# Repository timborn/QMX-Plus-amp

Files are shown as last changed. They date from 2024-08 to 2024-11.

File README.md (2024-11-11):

# QMX-amp
The QMX+ is a very nice radio kit from QPR Labs
https://qrp-labs.com/

This amp is designed by Ron Taylor, WA7GIL.  It should fit inside the empty
space in the case.

doc/original-drawings shows the original design sketchs

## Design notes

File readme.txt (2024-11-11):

Mon Nov 11 14:53:17 MST 2024
----------------------------
Changed the name of this project to QMX-Plus-amp to remove confusion with QMX.

Mon Aug 19 12:31:12 MST 2024
----------------------------
- silk screen is landing in all kinds of unhelpful places
- RF paths need wide copper.  How wide?  Figure out netclasses
- +12V probably needs a wide path as well for all that current (HOW MUCH?)
- want K1 & K2 to be *identical* even tho they appear in multiple schematic
  pages.  I want the control signals on one, and the RF paths on another.
  So far all I get are complaints about duplicate symbols, even when I 
  copy / paste special.

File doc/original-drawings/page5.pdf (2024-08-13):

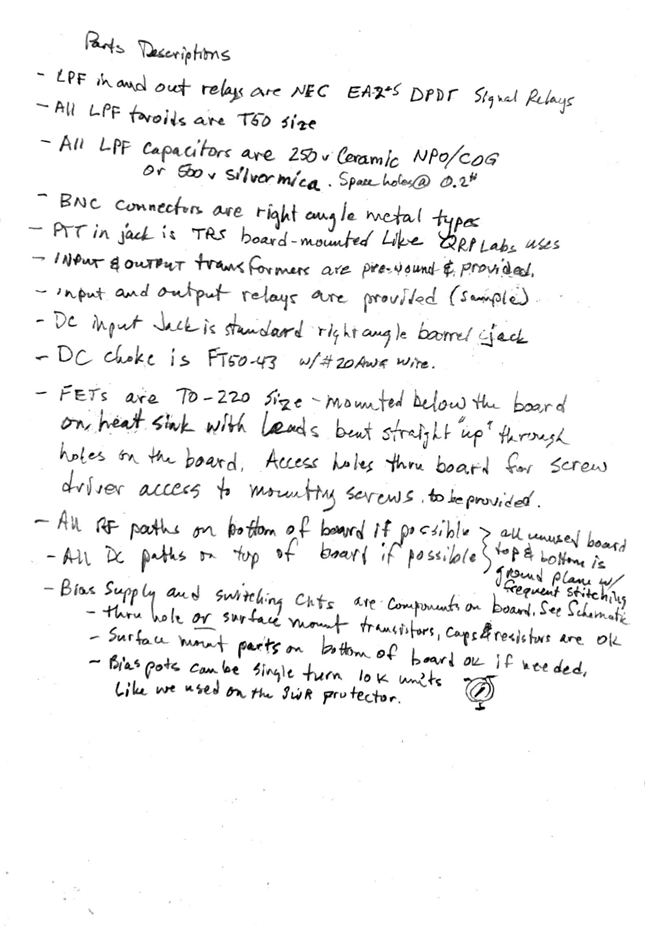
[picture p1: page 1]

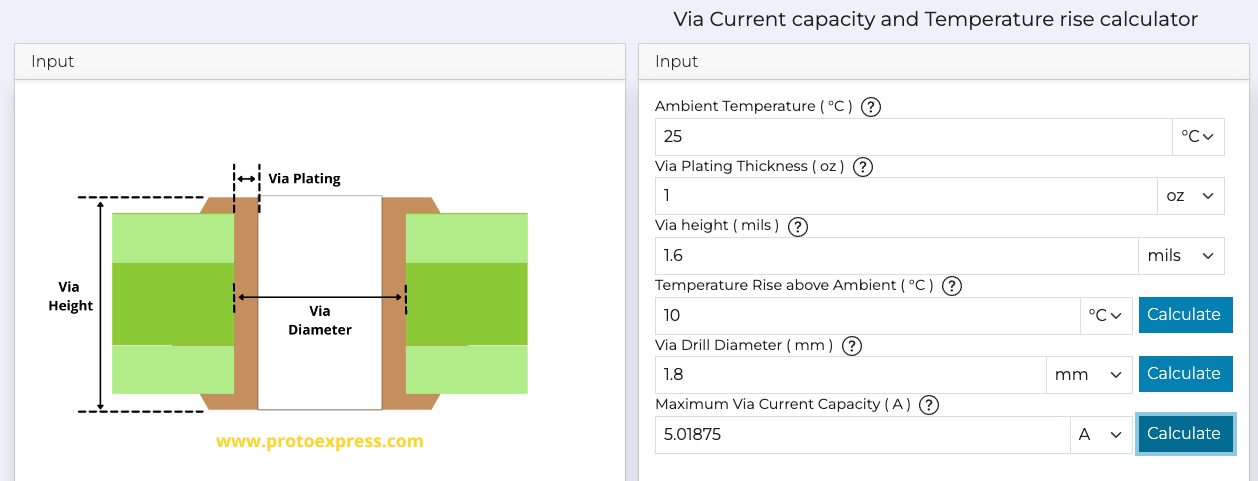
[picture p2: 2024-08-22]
doc/ViaCalcFor5APwr_designertools.app.protoexpress.com.jpg

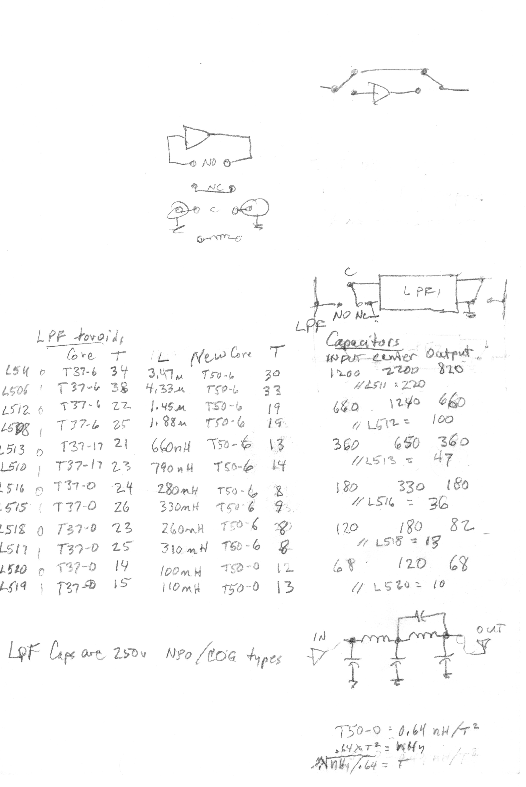
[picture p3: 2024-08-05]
doc/original-drawings/page6.jpg

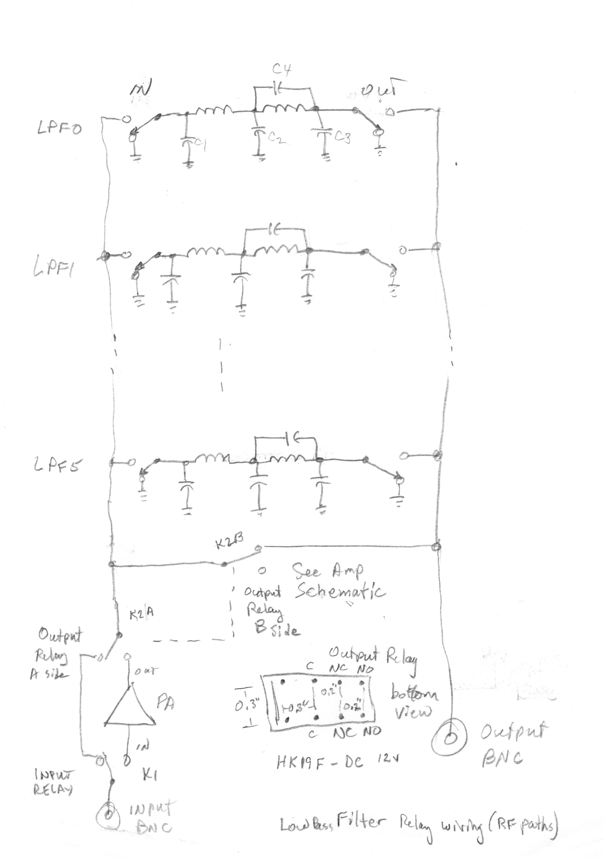
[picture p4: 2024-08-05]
doc/original-drawings/page2.jpg

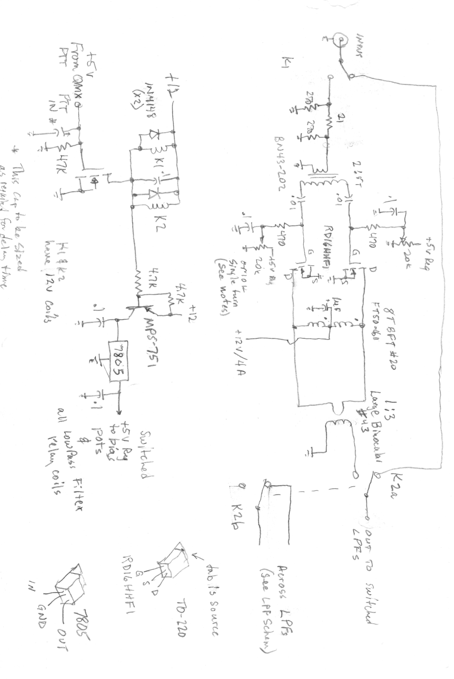
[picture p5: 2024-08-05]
doc/original-drawings/page4.jpg

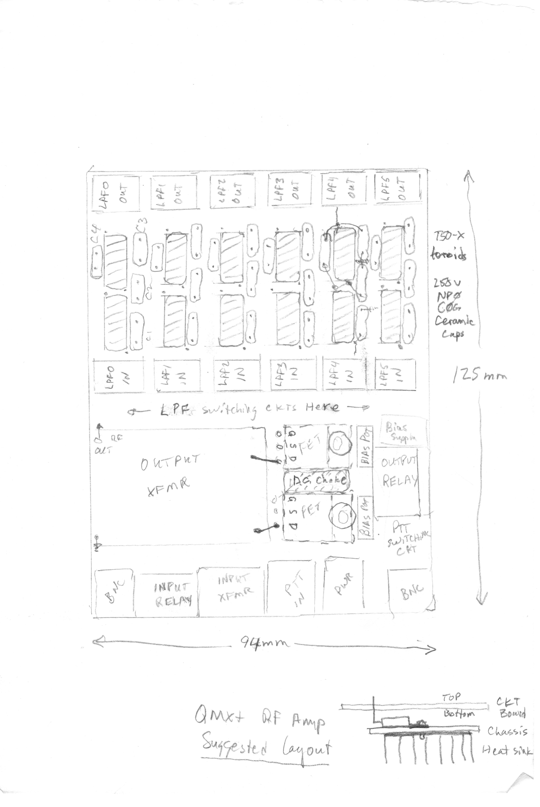
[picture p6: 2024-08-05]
doc/original-drawings/page3.jpg

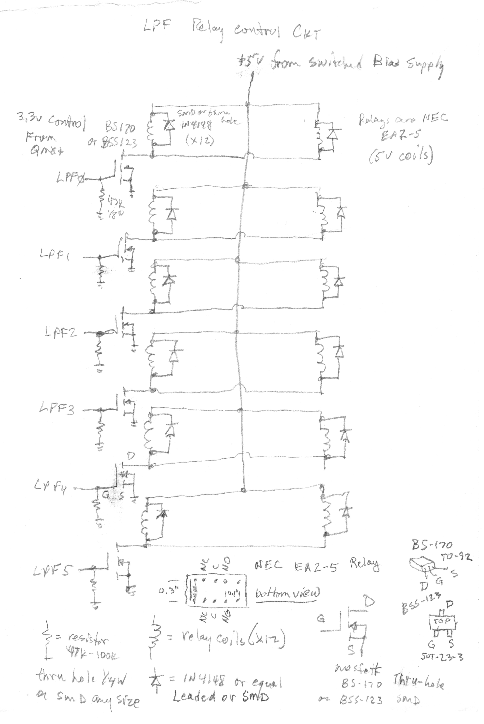
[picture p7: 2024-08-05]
doc/original-drawings/page1.jpg

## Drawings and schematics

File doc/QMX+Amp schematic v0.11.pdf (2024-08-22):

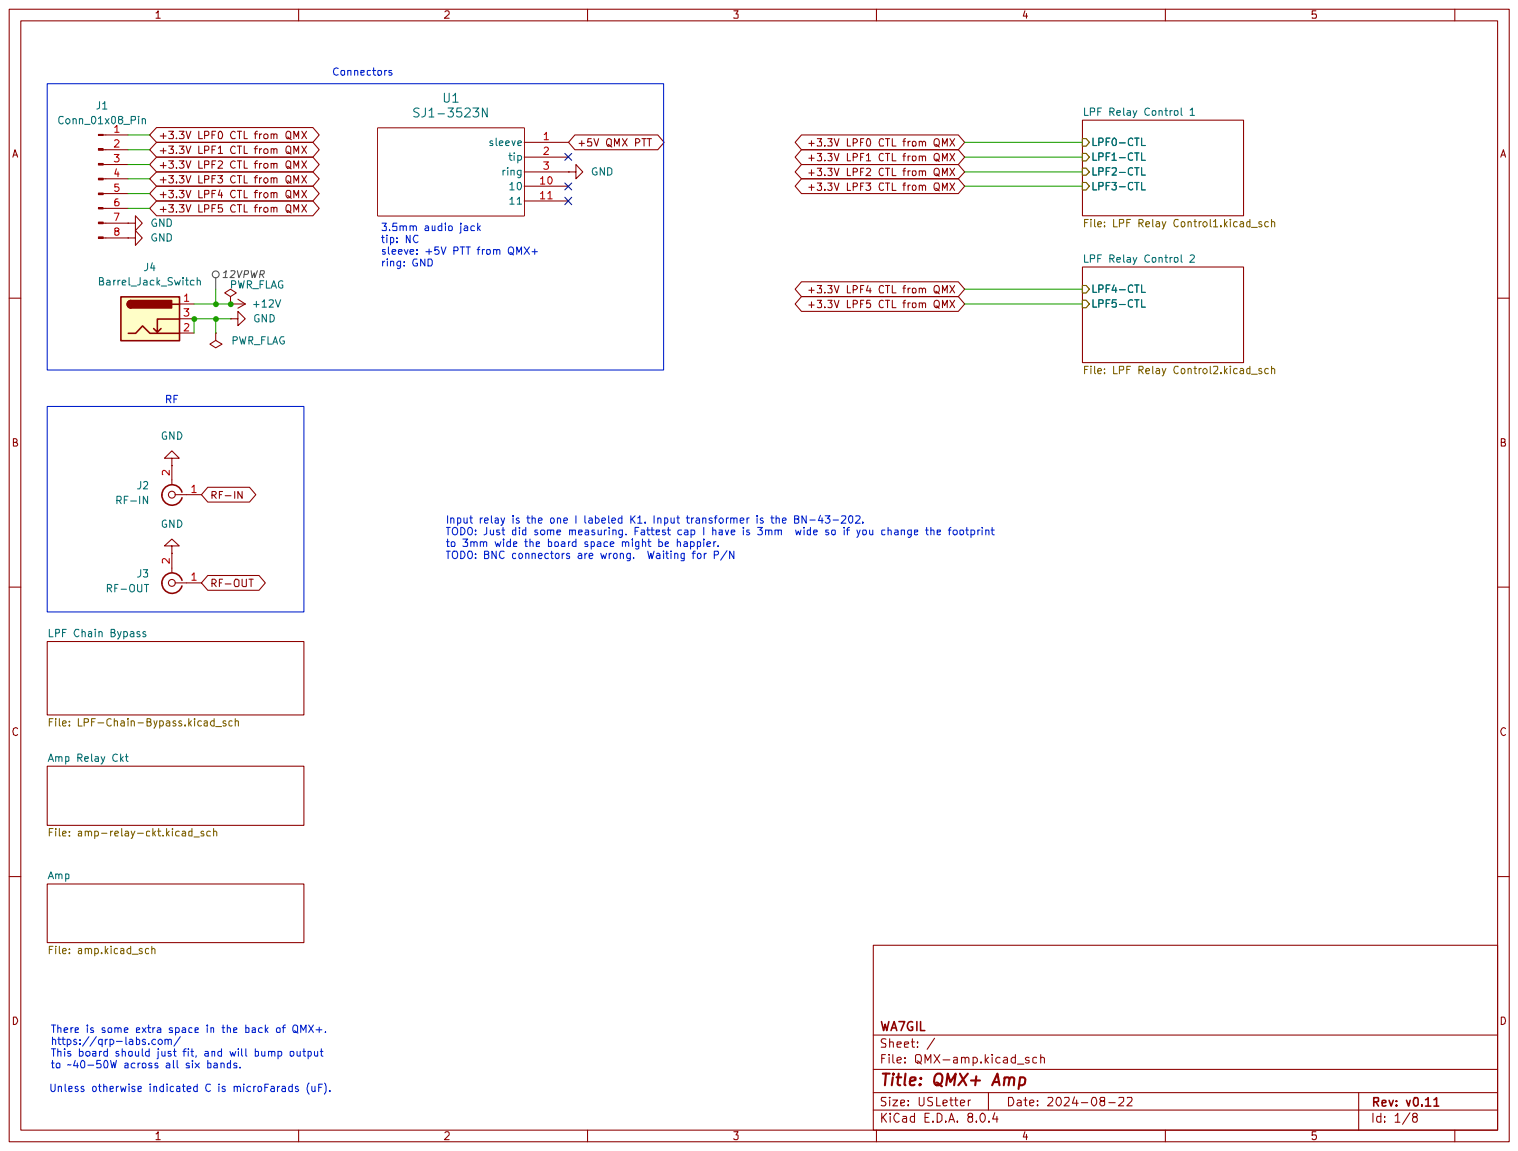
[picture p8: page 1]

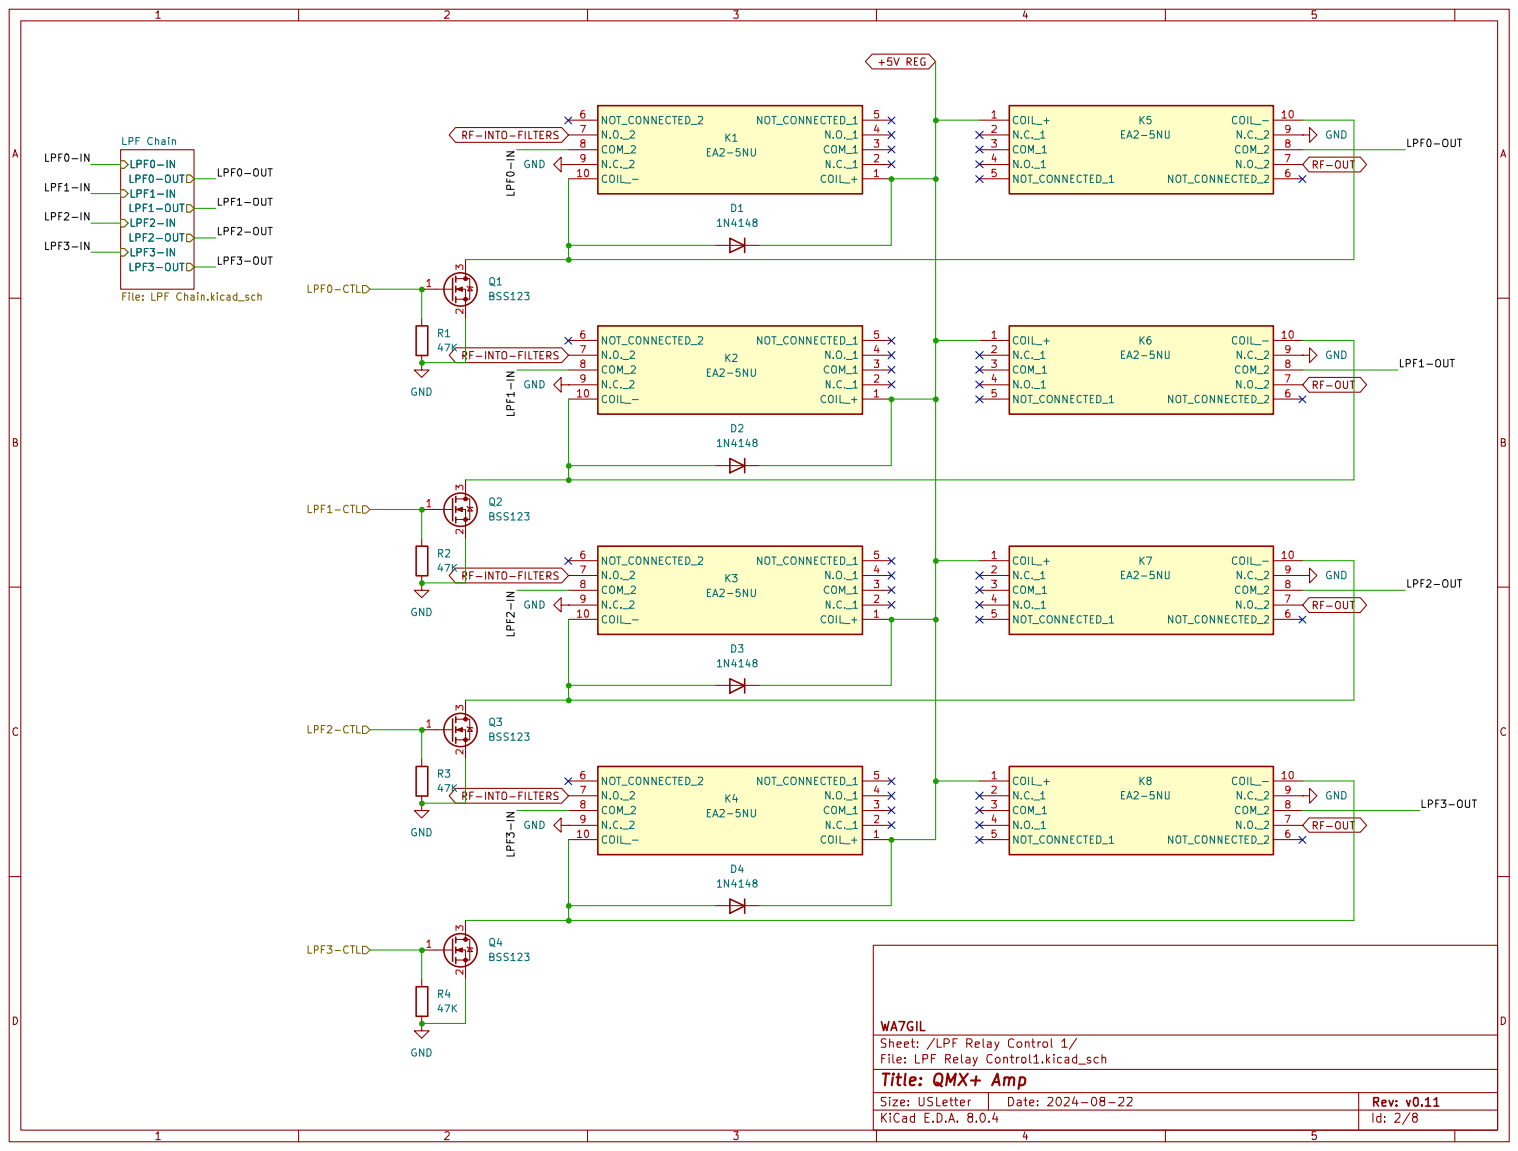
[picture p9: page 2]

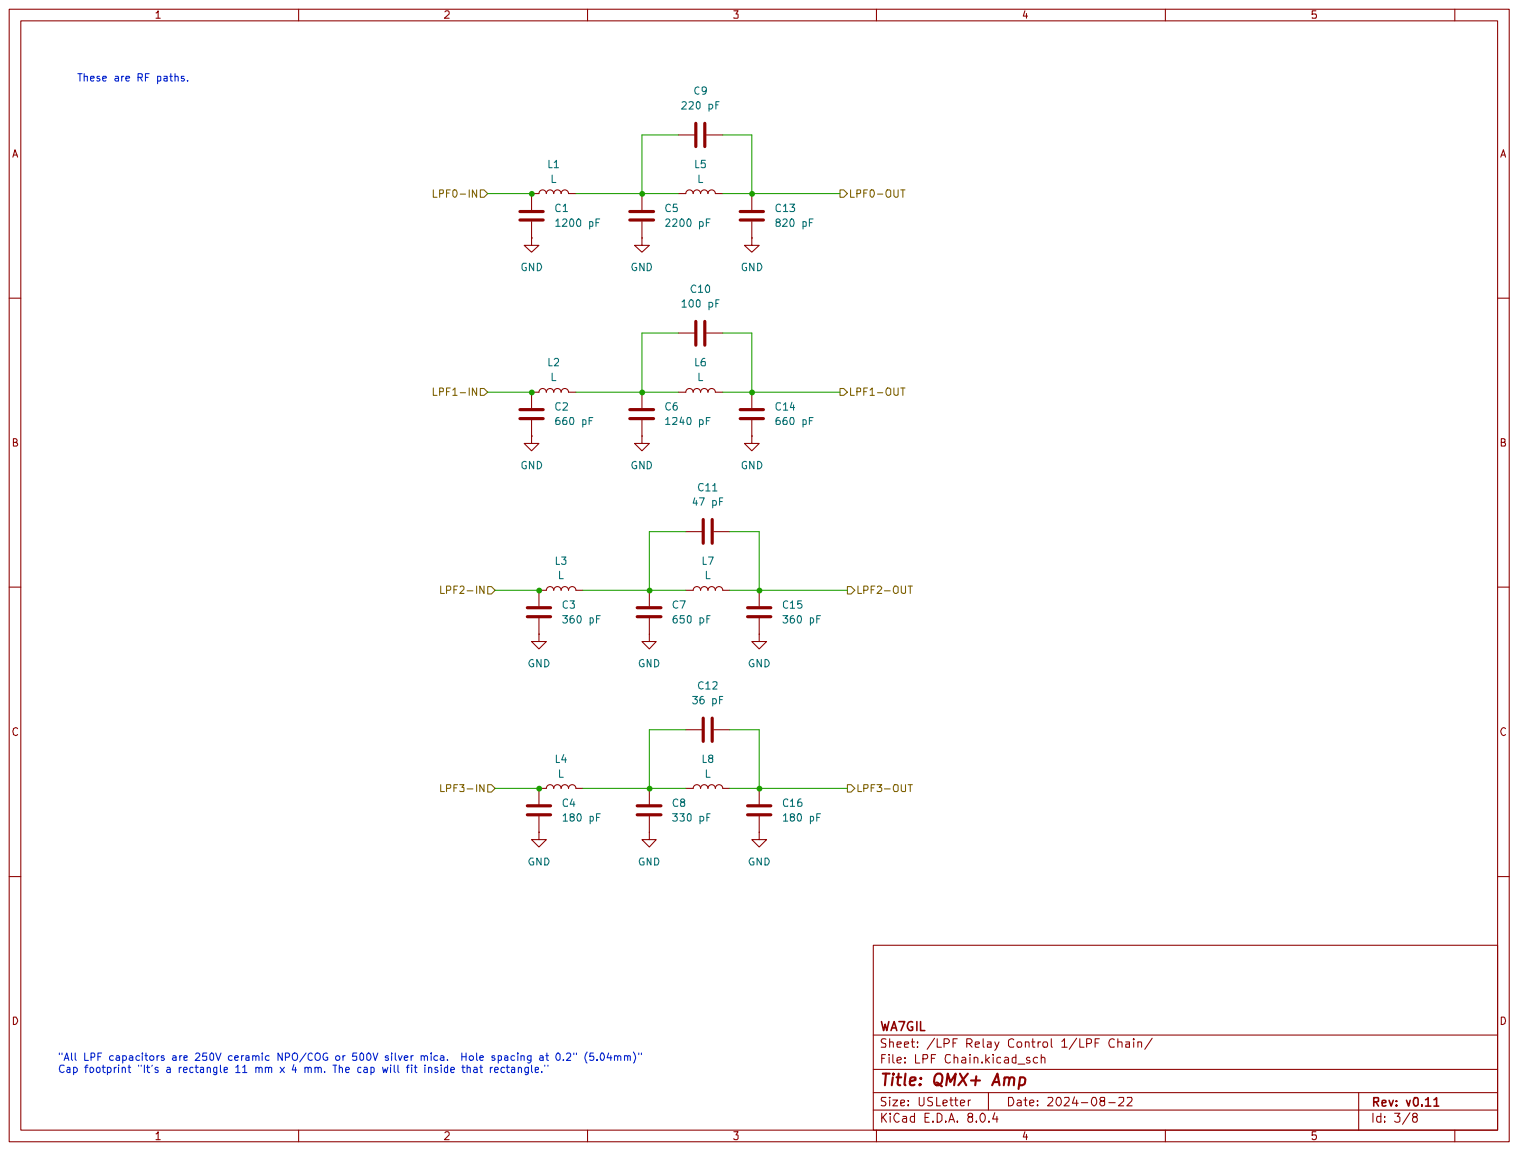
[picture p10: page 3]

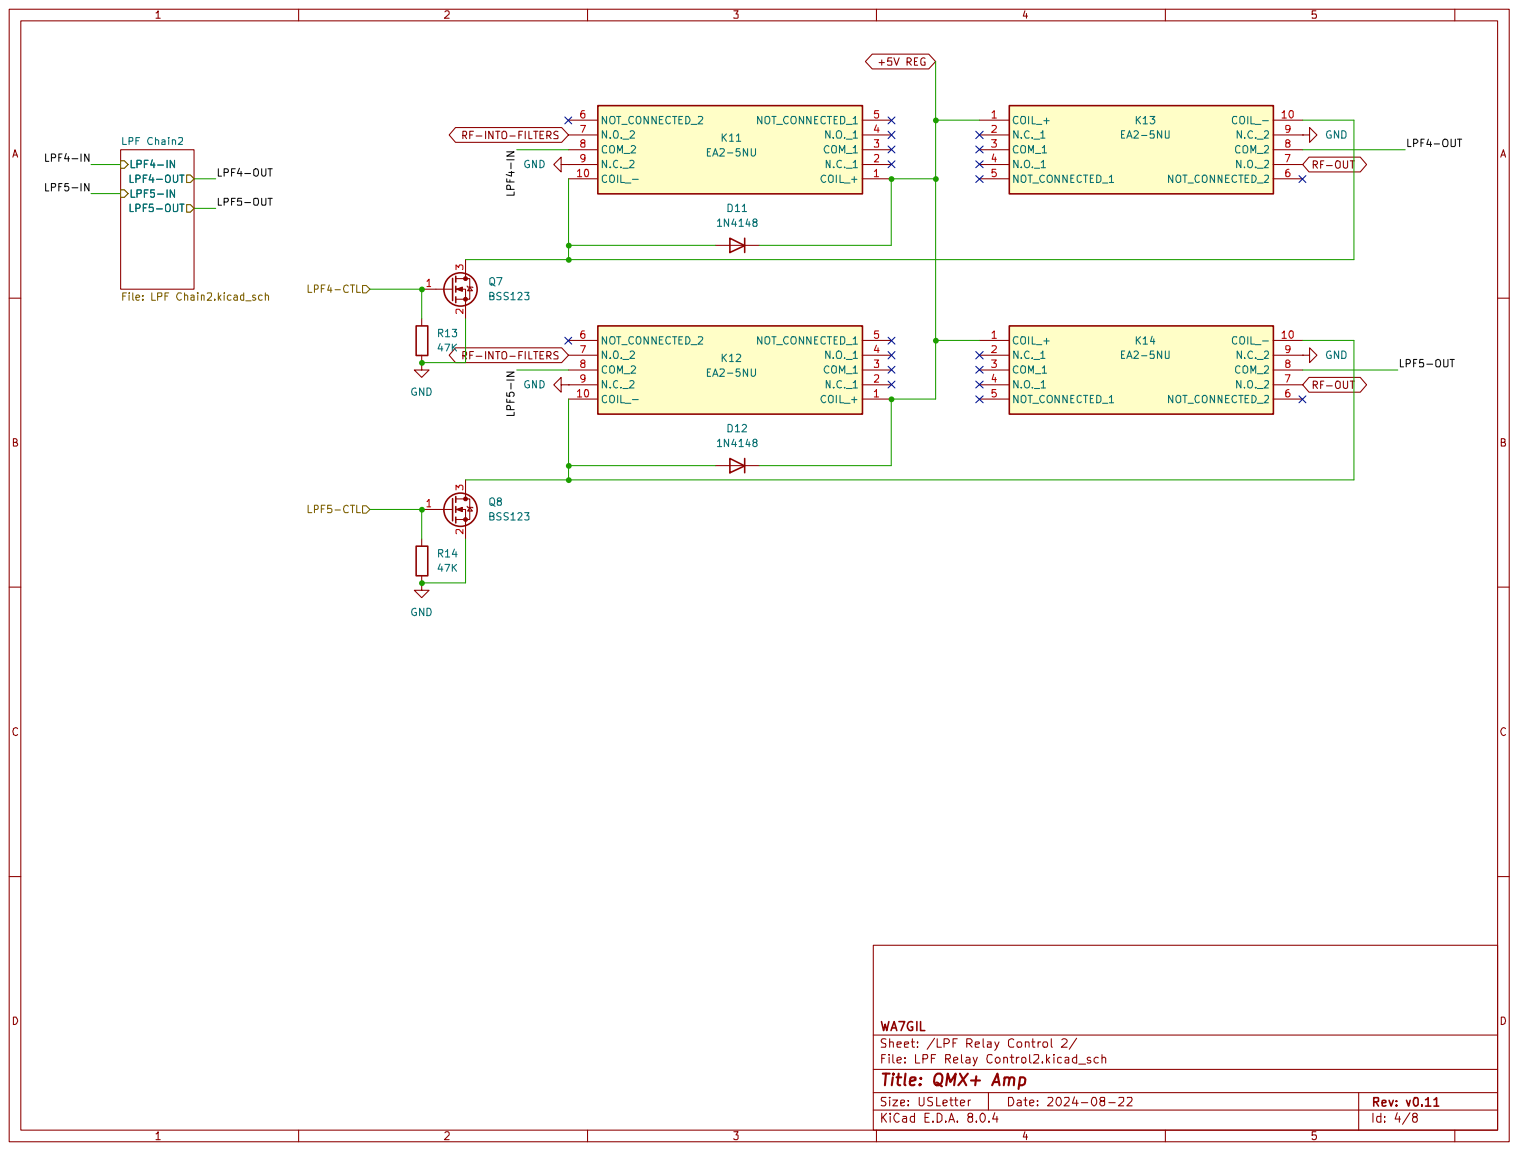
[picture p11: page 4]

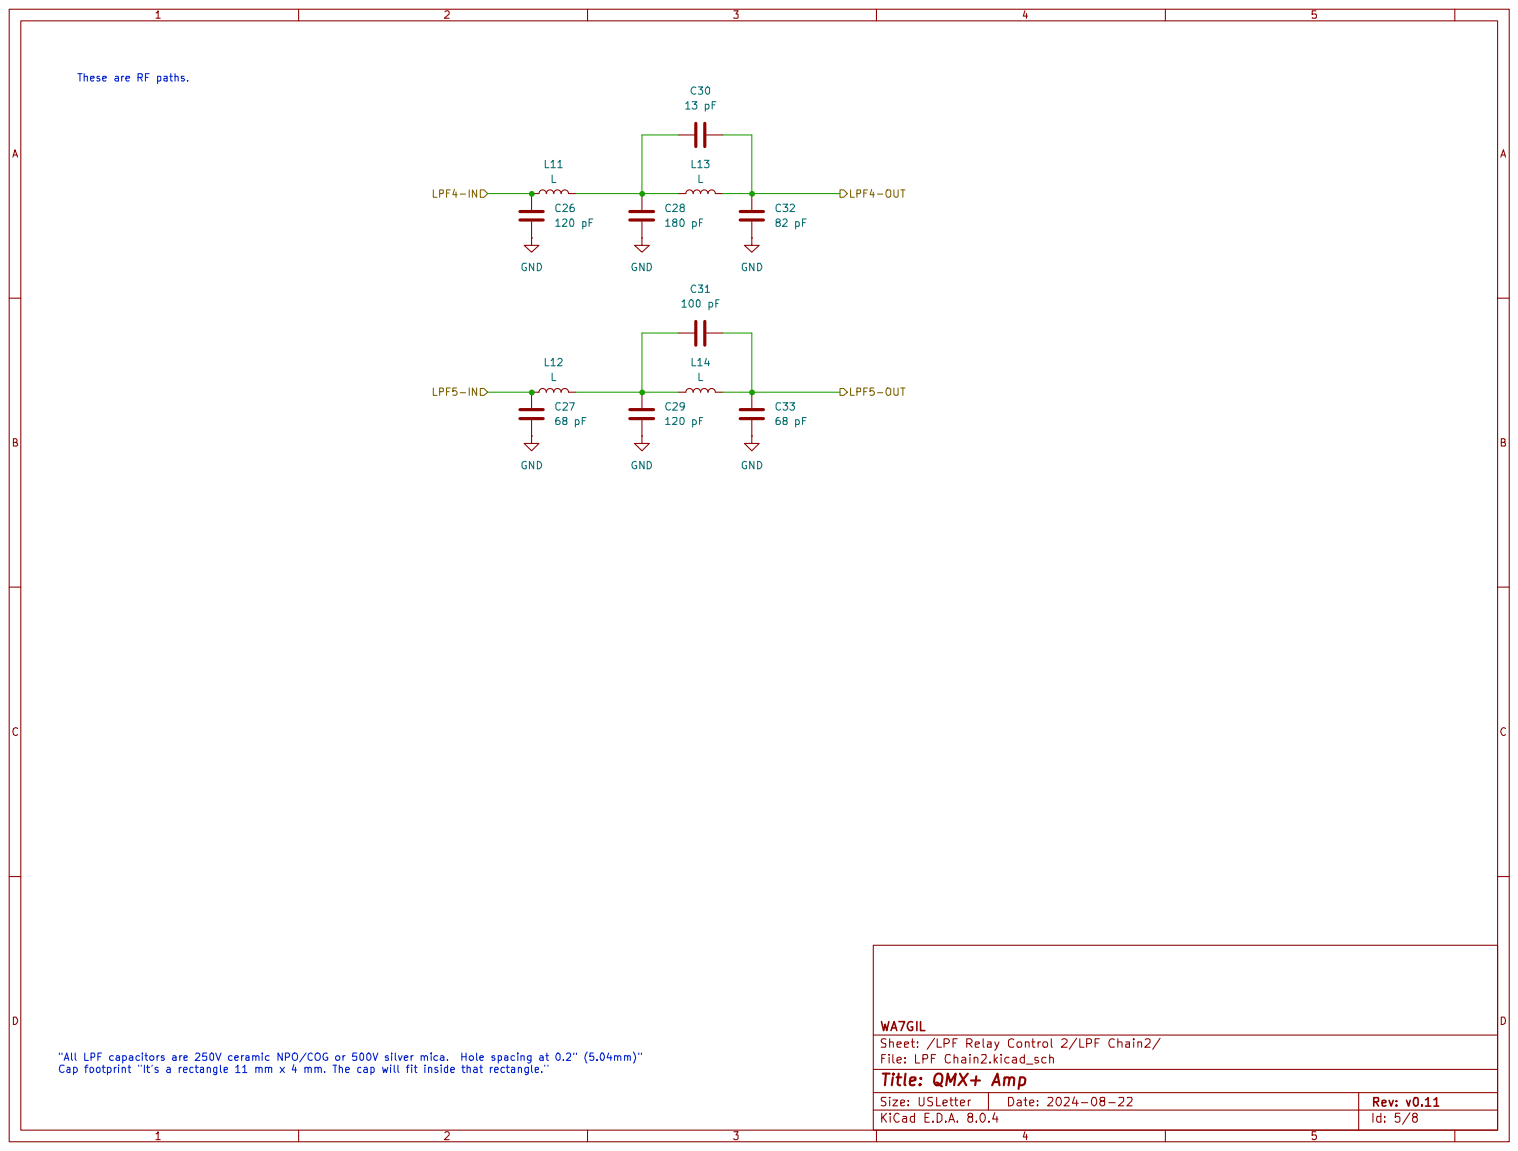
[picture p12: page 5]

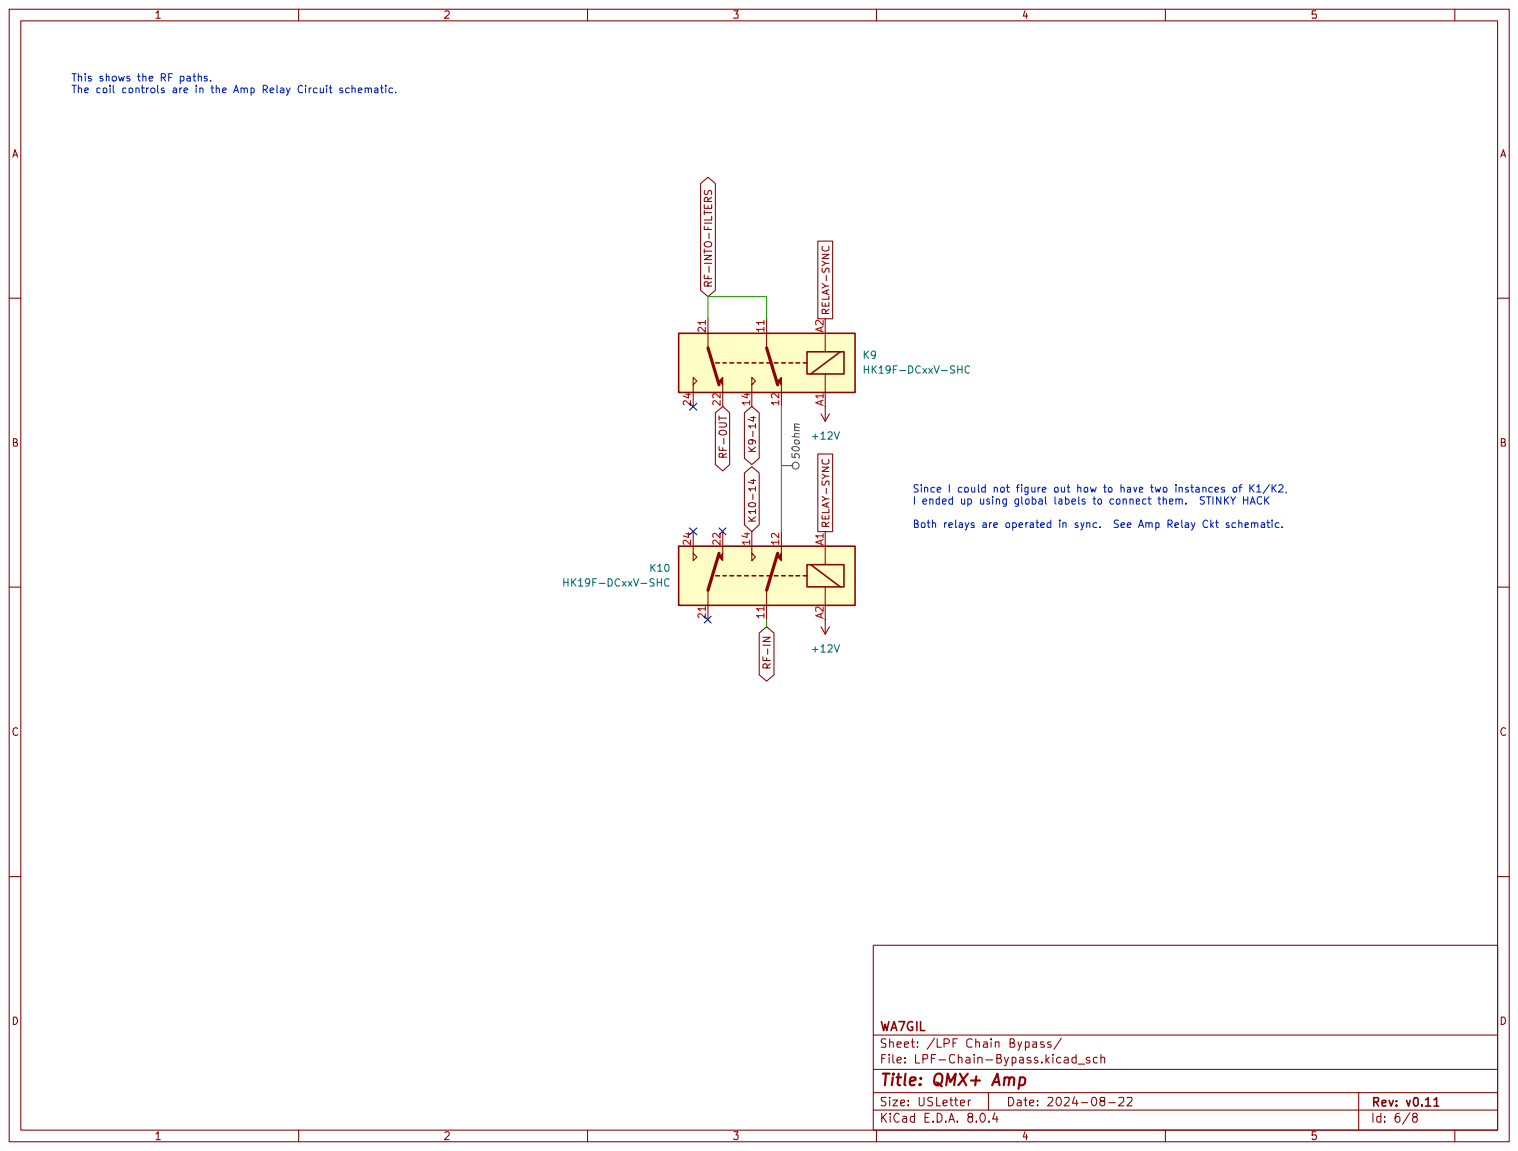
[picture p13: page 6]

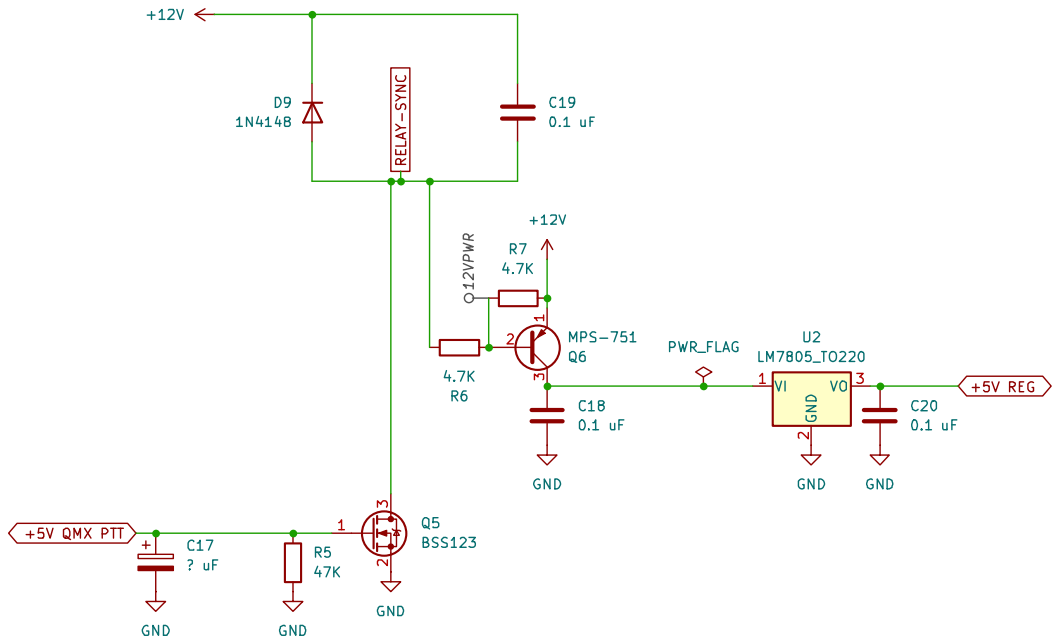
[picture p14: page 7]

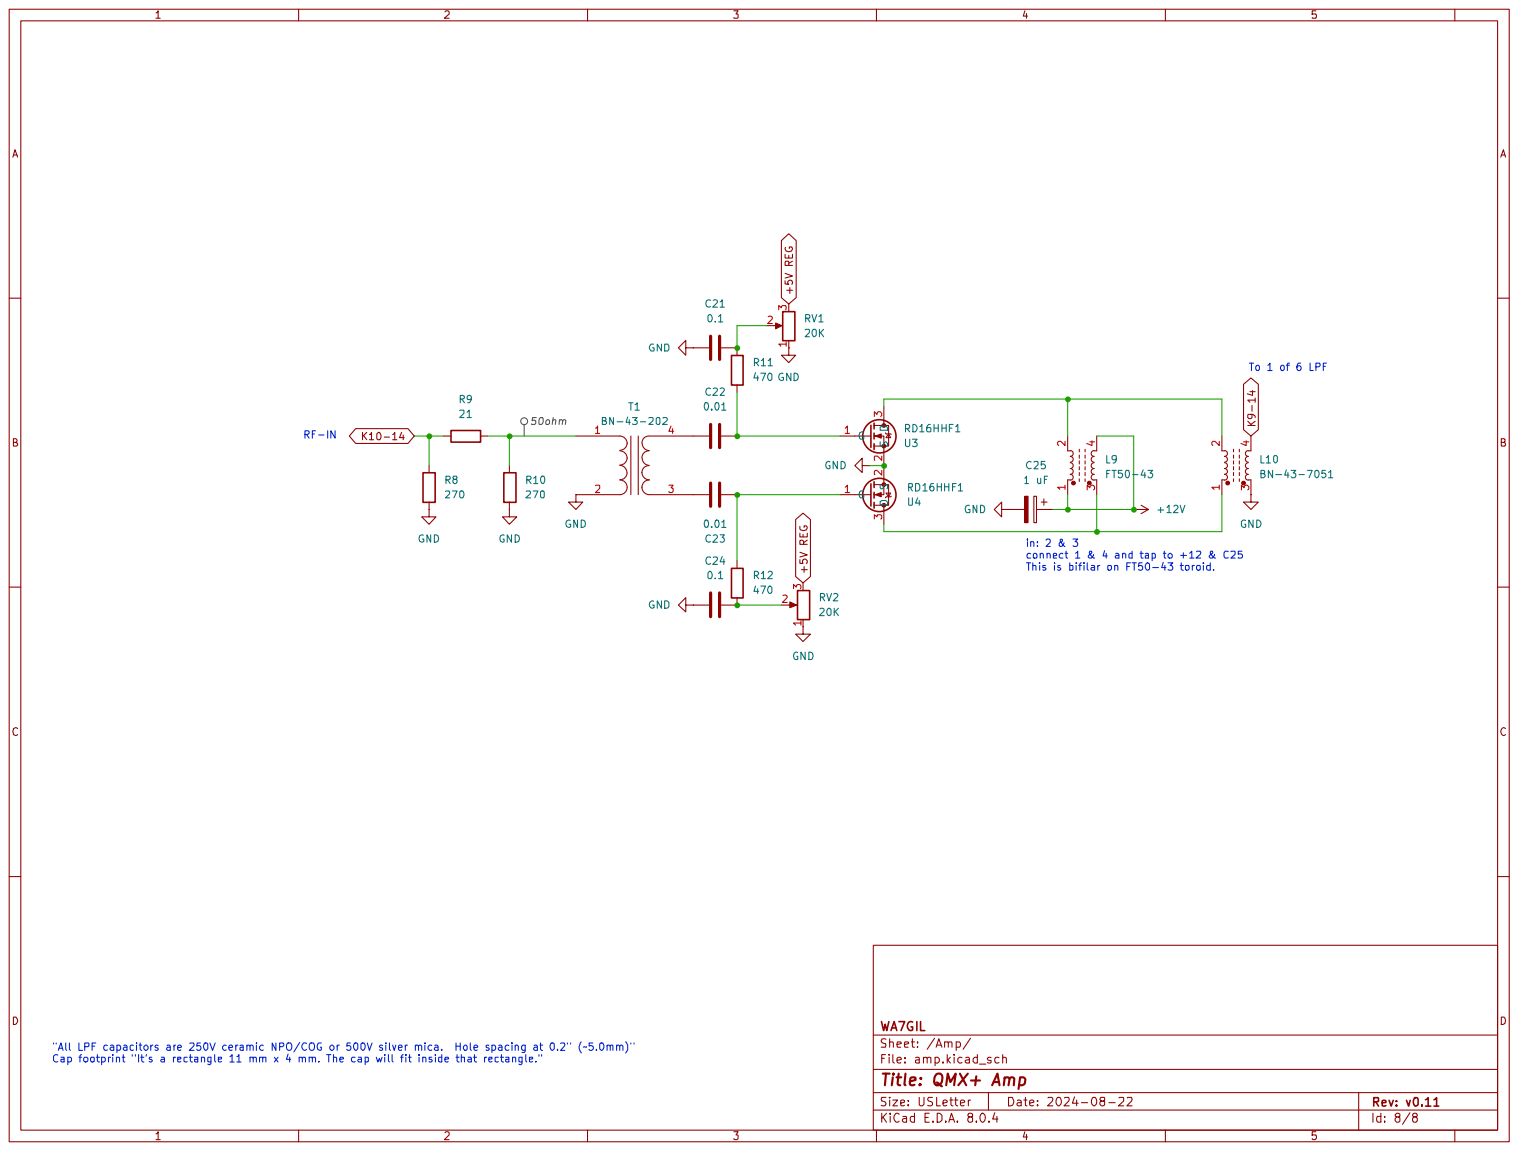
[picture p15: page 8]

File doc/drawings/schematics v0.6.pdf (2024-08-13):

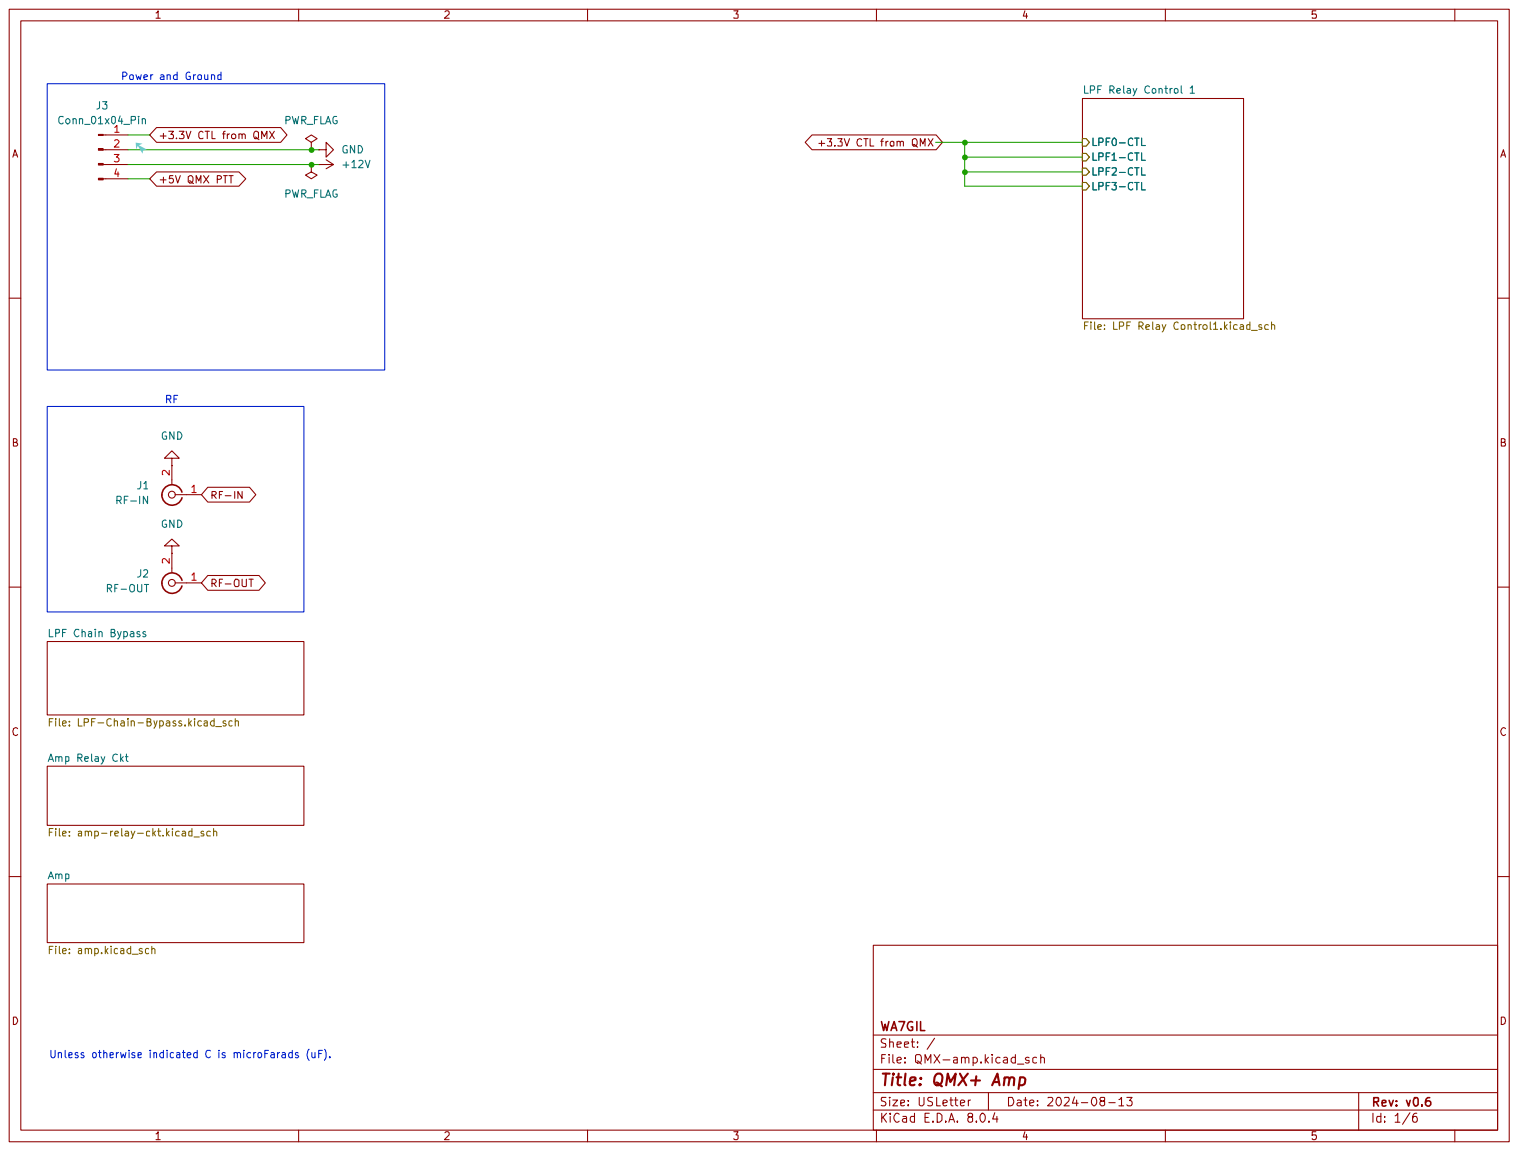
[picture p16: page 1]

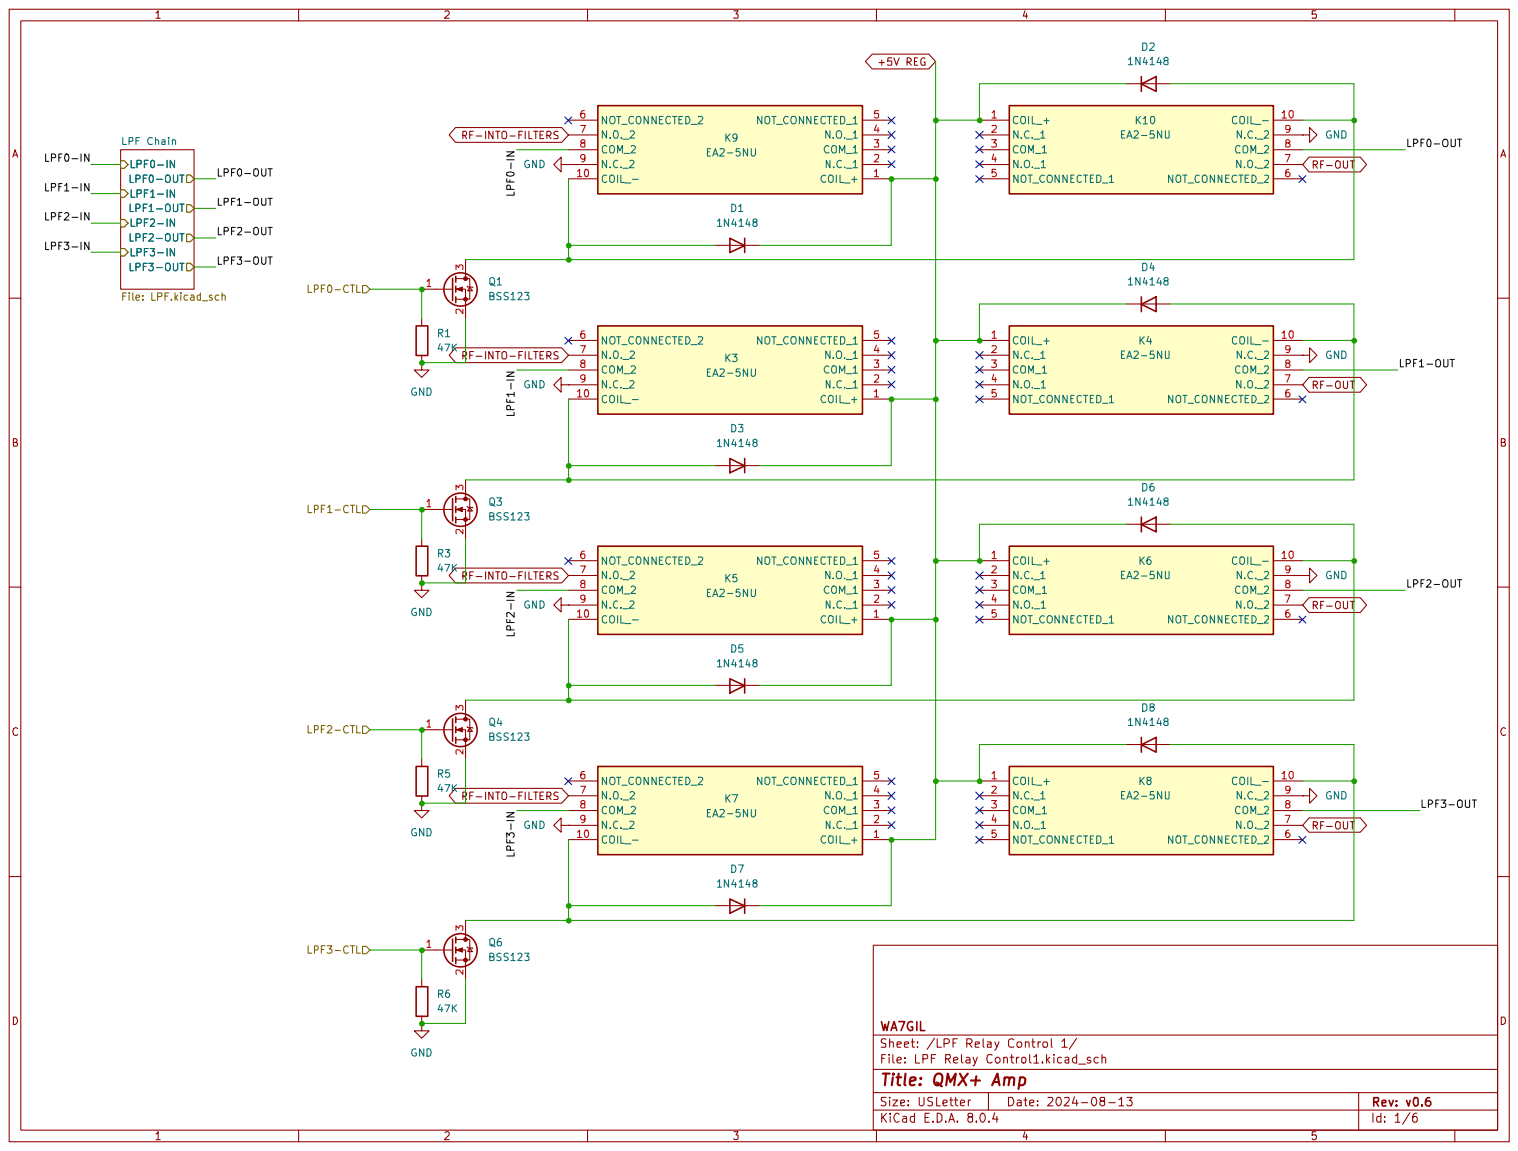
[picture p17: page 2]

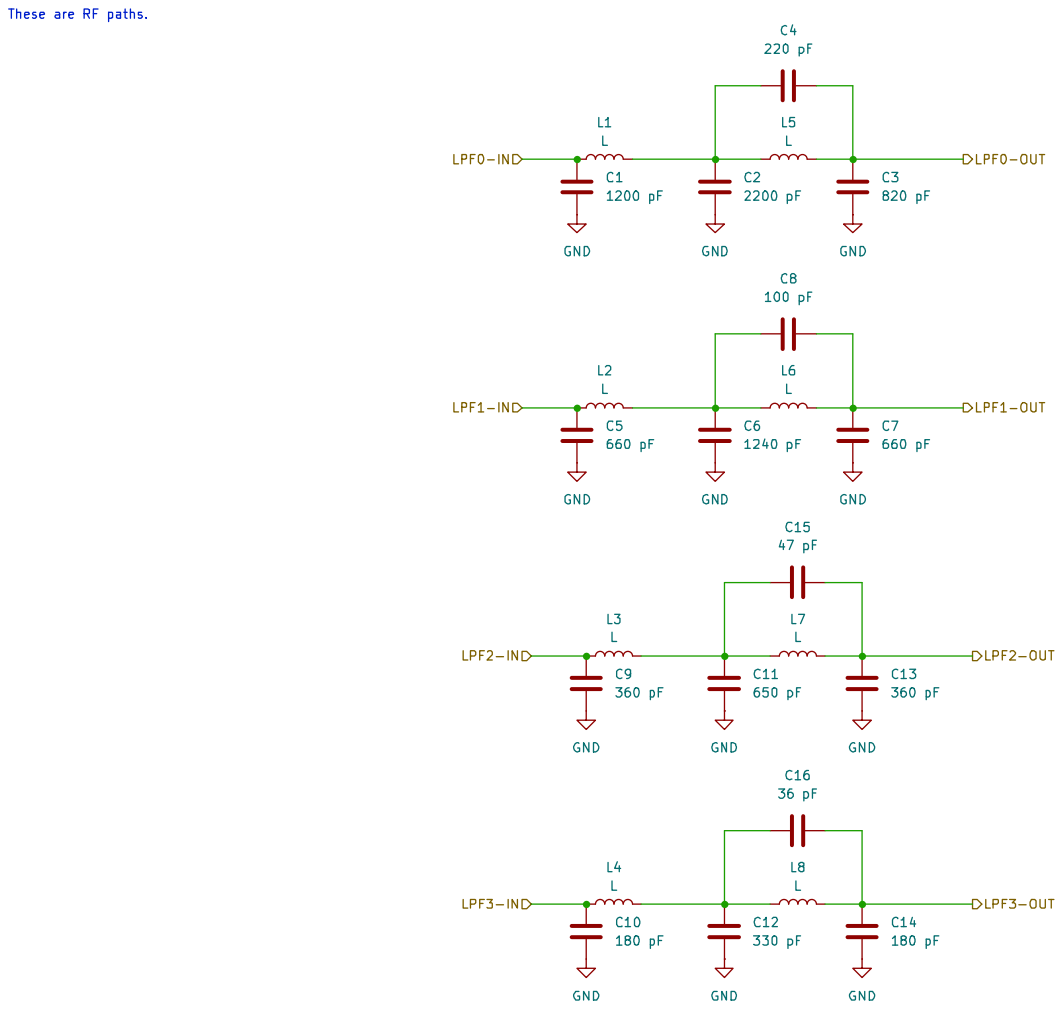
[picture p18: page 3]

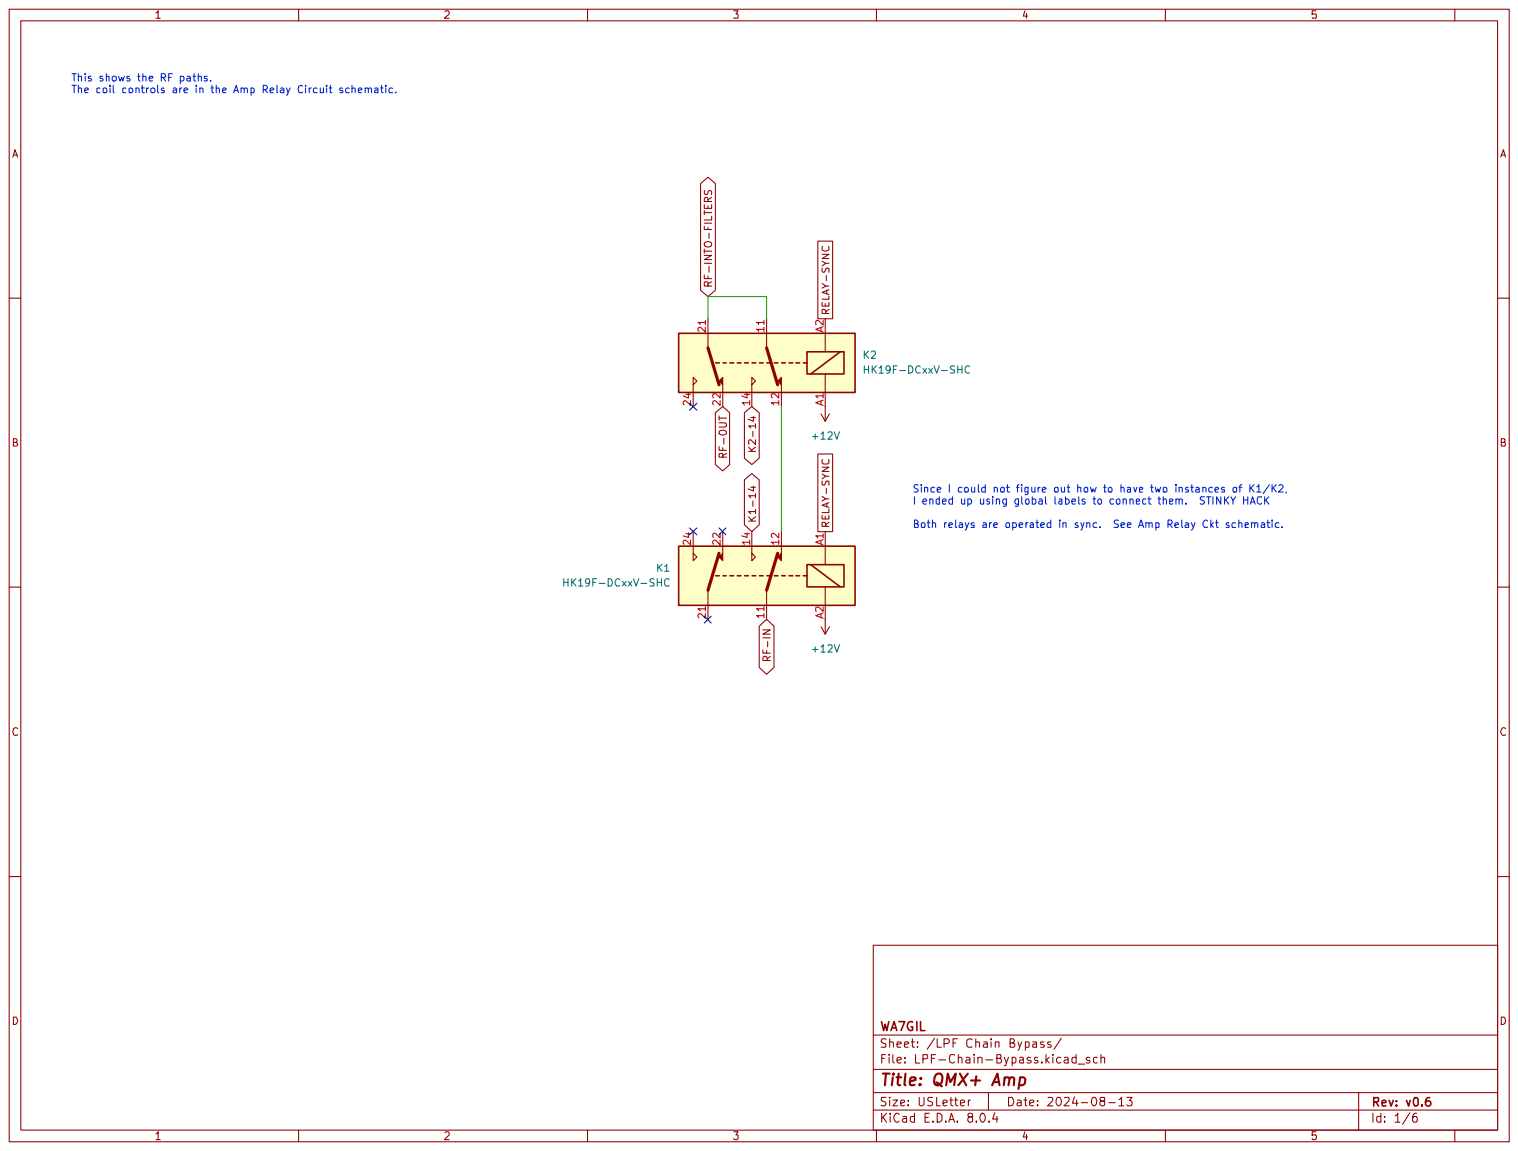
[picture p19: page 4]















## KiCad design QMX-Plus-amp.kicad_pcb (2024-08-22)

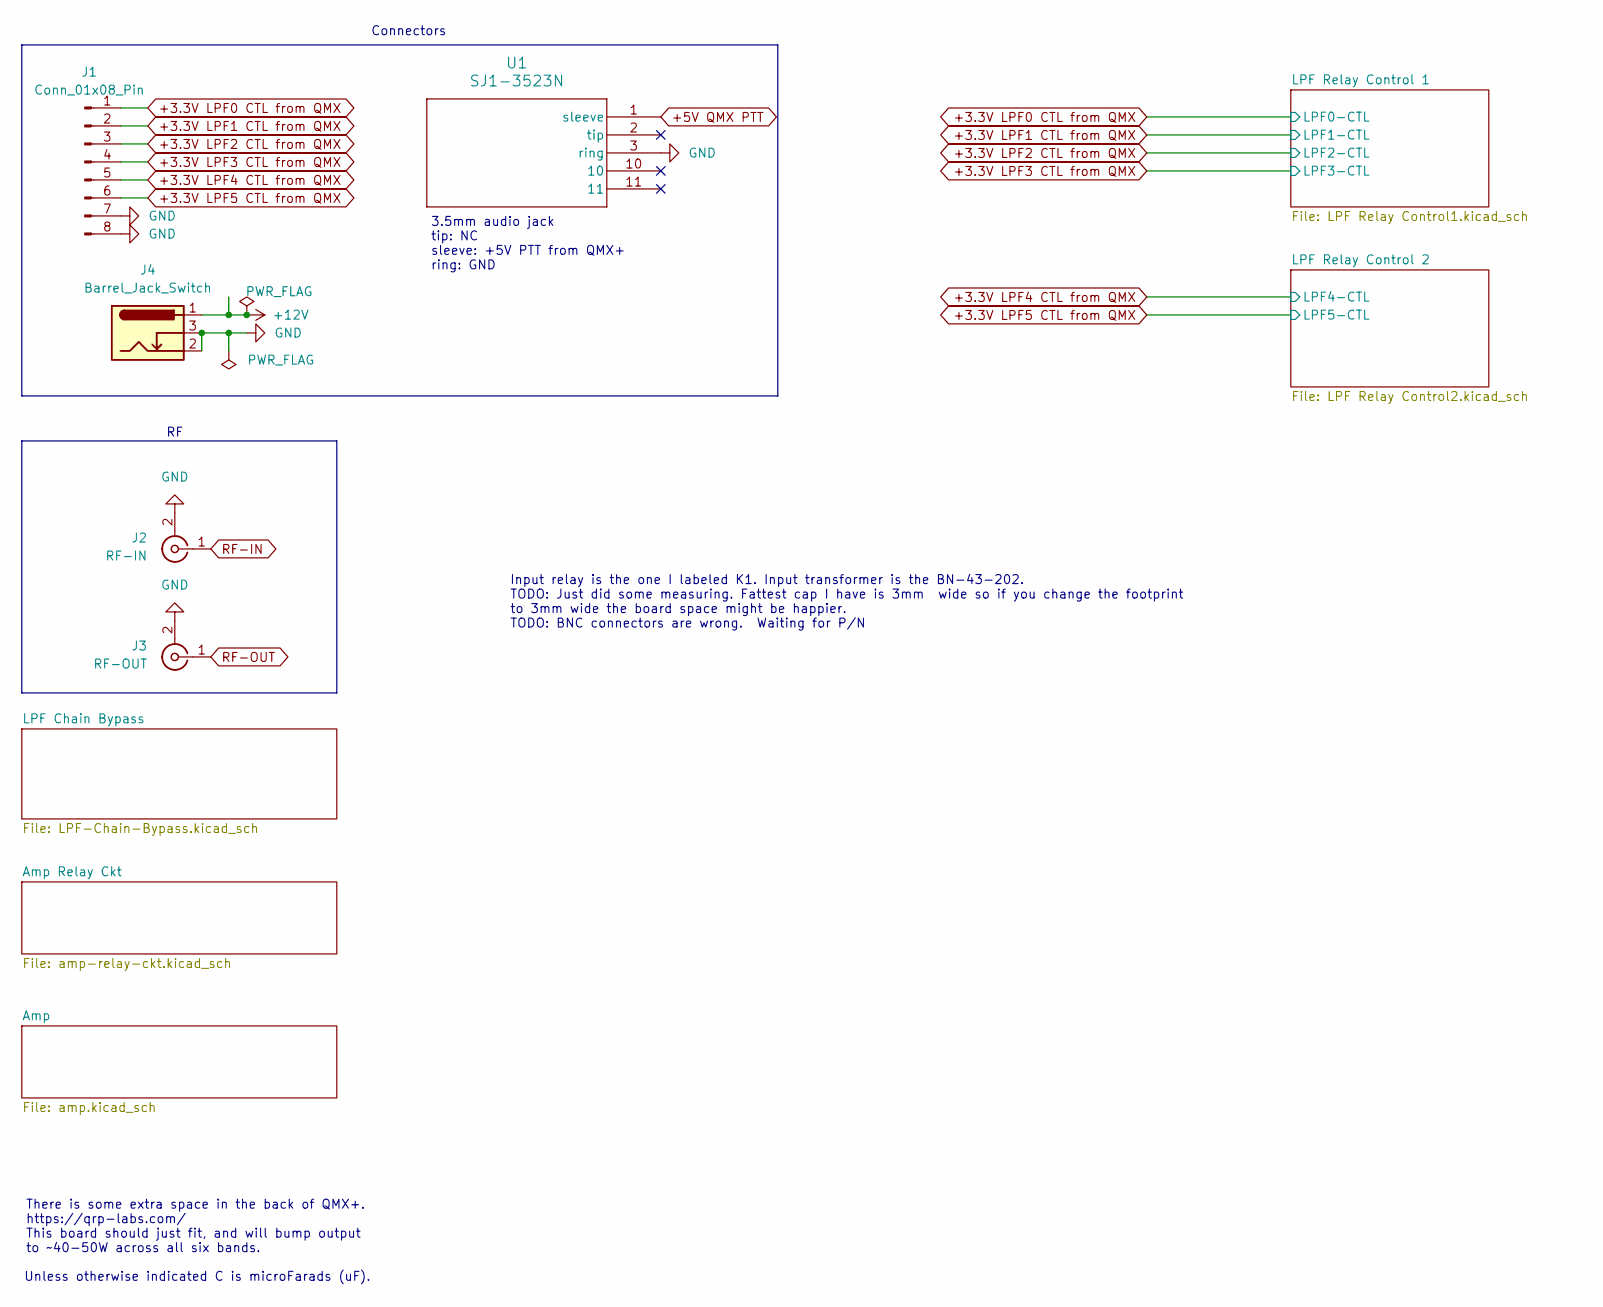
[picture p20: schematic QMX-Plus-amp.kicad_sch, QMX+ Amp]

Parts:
J1: Conn_01x08_Pin; PinHeader_1x08_P1.00mm_Horizontal
J2: RF-IN; BNC_Amphenol_B6252HB-NPP3G-50_Horizontal
J3: RF-OUT; BNC_Amphenol_B6252HB-NPP3G-50_Horizontal
J4: Barrel_Jack_Switch; BarrelJack_Horizontal
U1: SJ1-3523N; SJ1-3523N_CUD

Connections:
+3.3V LPF0 CTL from QMX: J1.1; also elsewhere on the board
+3.3V LPF1 CTL from QMX: J1.2; also elsewhere on the board
+3.3V LPF2 CTL from QMX: J1.3; also elsewhere on the board
+3.3V LPF3 CTL from QMX: J1.4; also elsewhere on the board
+3.3V LPF4 CTL from QMX: J1.5; also elsewhere on the board
+3.3V LPF5 CTL from QMX: J1.6; also elsewhere on the board
+5V QMX PTT: U1.1 (sleeve); also elsewhere on the board
+12V: J4.1; also elsewhere on the board
GND: J1.7, J1.8, J2.2 (Ext), J3.2 (Ext), J4.2, J4.3, U1.3 (ring); also elsewhere on the board
RF-IN: J2.1 (In); also elsewhere on the board
RF-OUT: J3.1 (In); also elsewhere on the board

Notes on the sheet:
Unless otherwise indicated C is microFarads (uF).
Connectors
Input relay is the one I labeled K1. Input transformer is the BN-43-202. TODO: Just did some measuring. Fattest cap I have is 3mm wide so if you change the footprint to 3mm wide the board space might be happier. TODO: BNC connectors are wrong. Waiting for P/N
3.5mm audio jack tip: NC sleeve: +5V PTT from QMX+ ring: GND
There is some extra space in the back of QMX+. https://qrp-labs.com/ This board should just fit, and will bump output to ~40-50W across all six bands.

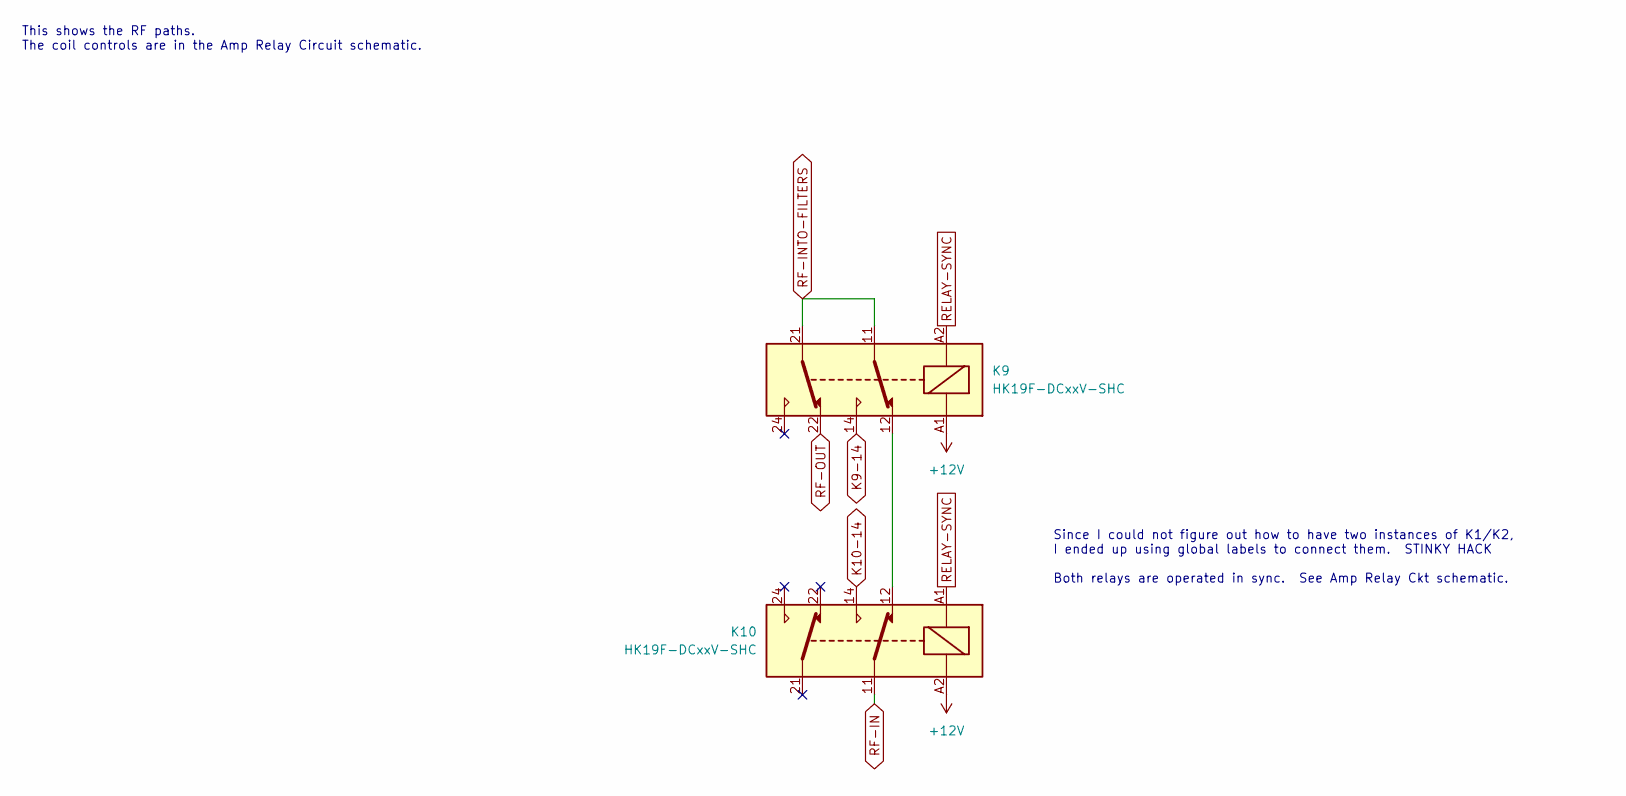
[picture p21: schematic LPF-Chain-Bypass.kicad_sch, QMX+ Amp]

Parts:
K9, K10: HK19F-DCxxV-SHC; Relay_DPDT_Finder_30.22

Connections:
+12V: K9.A1, K10.A2; also elsewhere on the board
K9-14: K9.14; also elsewhere on the board
K10-14: K10.14; also elsewhere on the board
unnamed: K9.12, K10.12
RELAY-SYNC: K9.A2, K10.A1; also elsewhere on the board
RF-IN: K10.11; also elsewhere on the board
RF-INTO-FILTERS: K9.11, K9.21; also elsewhere on the board
RF-OUT: K9.22; also elsewhere on the board

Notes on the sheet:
Since I could not figure out how to have two instances of K1/K2, I ended up using global labels to connect them. STINKY HACK Both relays are operated in sync. See Amp Relay Ckt schematic.
This shows the RF paths. The coil controls are in the Amp Relay Circuit schematic.

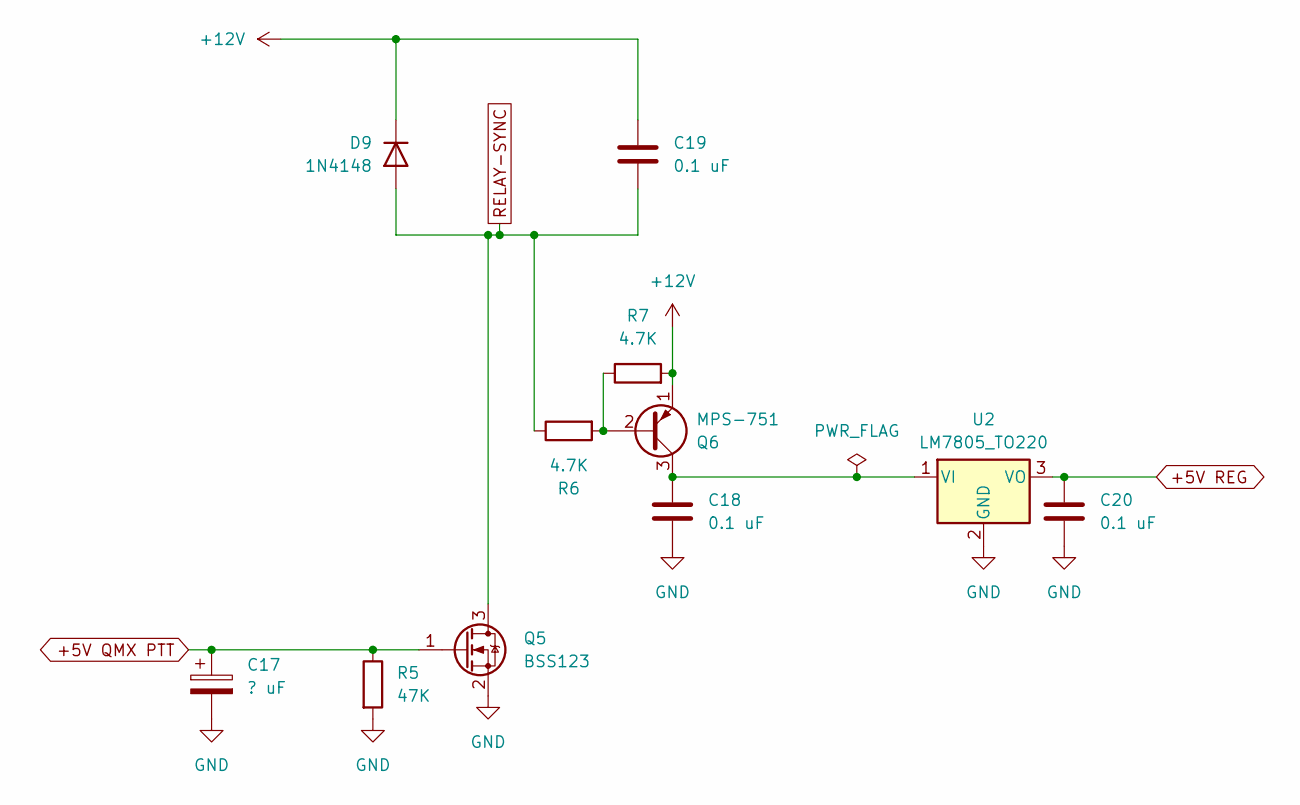
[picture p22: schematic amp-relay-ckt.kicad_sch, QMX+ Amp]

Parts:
C17: ? uF; C_Disc_D11.0mm_W3.0mm_P5.00mm
C18, C19, C20: 0.1 uF; R_0805_2012Metric_Pad1.20x1.40mm_HandSolder
D9: 1N4148; D_DO-34_SOD68_P7.62mm_Horizontal
Q5: BSS123; SOT-23
Q6: MPS-751; TO-92
R5: 47K; R_0805_2012Metric_Pad1.20x1.40mm_HandSolder
R6, R7: 4.7K; R_0805_2012Metric_Pad1.20x1.40mm_HandSolder
U2: LM7805_TO220; TO-220-3_Vertical

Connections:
+5V QMX PTT: C17.1, Q5.1 (G), R5.1; also elsewhere on the board
+5V REG: C20.1, U2.3 (VO); also elsewhere on the board
+12V: C19.1, D9.1 (K), Q6.1 (E), R7.2; also elsewhere on the board
GND: C17.2, C18.2, C20.2, Q5.2 (S), R5.2, U2.2 (GND); also elsewhere on the board
unnamed: Q6.2 (B), R6.2, R7.1
unnamed: C18.1, Q6.3 (C), U2.1 (VI)
RELAY-SYNC: C19.2, D9.2 (A), Q5.3 (D), R6.1; also elsewhere on the board

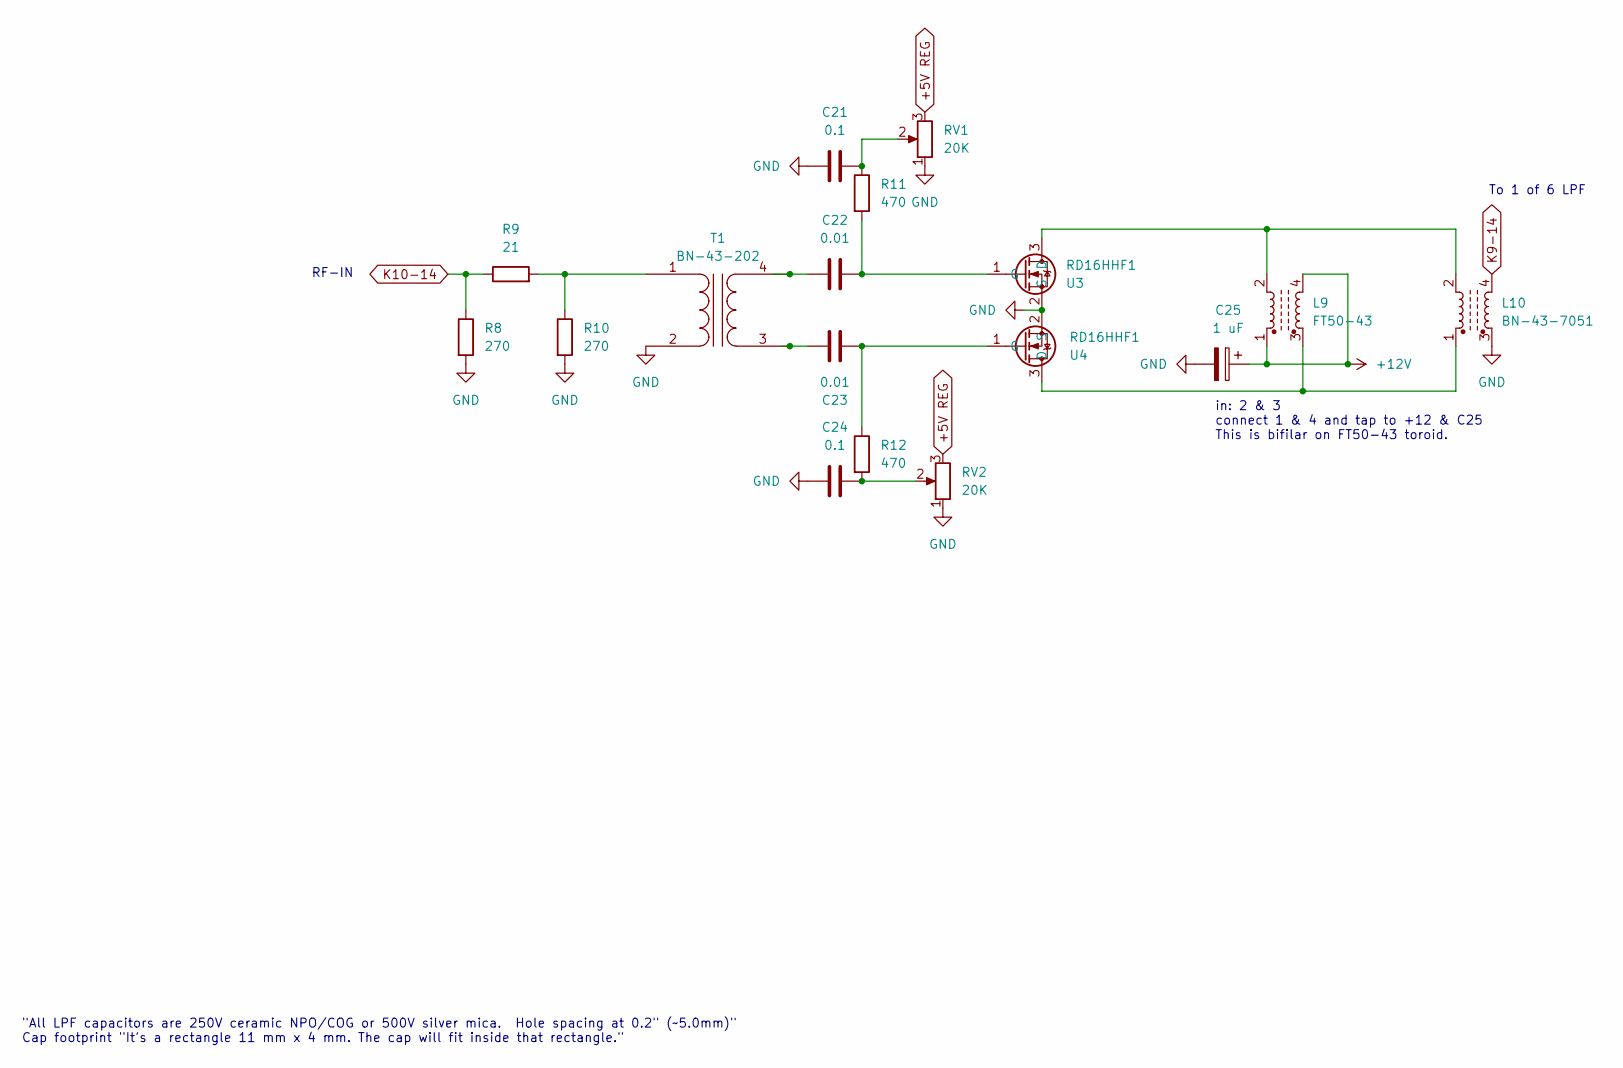
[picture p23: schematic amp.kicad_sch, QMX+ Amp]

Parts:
C21, C24: 0.1; R_0805_2012Metric_Pad1.20x1.40mm_HandSolder
C22, C23: 0.01; R_0805_2012Metric_Pad1.20x1.40mm_HandSolder
C25: 1 uF; C_Disc_D11.0mm_W3.0mm_P5.00mm
L9: FT50-43; Toroid_T50_Vertical_L14.0mm_W5.6mm_4pins
L10: BN-43-7051; BN-43-7051-FLAT
R8, R10: 270; R_Axial_DIN0207_L6.3mm_D2.5mm_P2.54mm_Vertical
R9: 21; R_Axial_DIN0207_L6.3mm_D2.5mm_P2.54mm_Vertical
R11, R12: 470; R_0805_2012Metric_Pad1.20x1.40mm_HandSolder
RV1, RV2: 20K; Potentiometer_Piher_PT-10-V05_Vertical
T1: BN-43-202; BN-43-202-FLAT
U3, U4: RD16HHF1; TO-220F-3_Horizontal_TabDown

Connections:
+5V REG: RV1.3, RV2.3; also elsewhere on the board
+12V: C25.1, L9.1, L9.4; also elsewhere on the board
GND: C21.1, C24.1, C25.2, L10.3, R8.2, R10.2, RV1.1, RV2.1, T1.2 (AB), U3.2 (S), U4.2 (S); also elsewhere on the board
K9-14: L10.4; also elsewhere on the board
K10-14: R8.1, R9.1; also elsewhere on the board
unnamed: C21.2, R11.1, RV1.2
unnamed: C24.2, R12.2, RV2.2
unnamed: R9.2, R10.1, T1.1 (AA)
unnamed: C23.1, T1.3 (SA)
unnamed: C22.1, T1.4 (SB)
unnamed: L9.2, L10.2, U3.3 (D)
unnamed: C22.2, R11.2, U3.1 (G)
unnamed: L9.3, L10.1, U4.3 (D)
unnamed: C23.2, R12.1, U4.1 (G)

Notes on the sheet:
To 1 of 6 LPF
"All LPF capacitors are 250V ceramic NPO/COG or 500V silver mica. Hole spacing at 0.2" (~5.0mm)" Cap footprint "It's a rectangle 11 mm x 4 mm. The cap will fit inside that rectangle."
RF-IN
in: 2 & 3 connect 1 & 4 and tap to +12 & C25 This is bifilar on FT50-43 toroid.

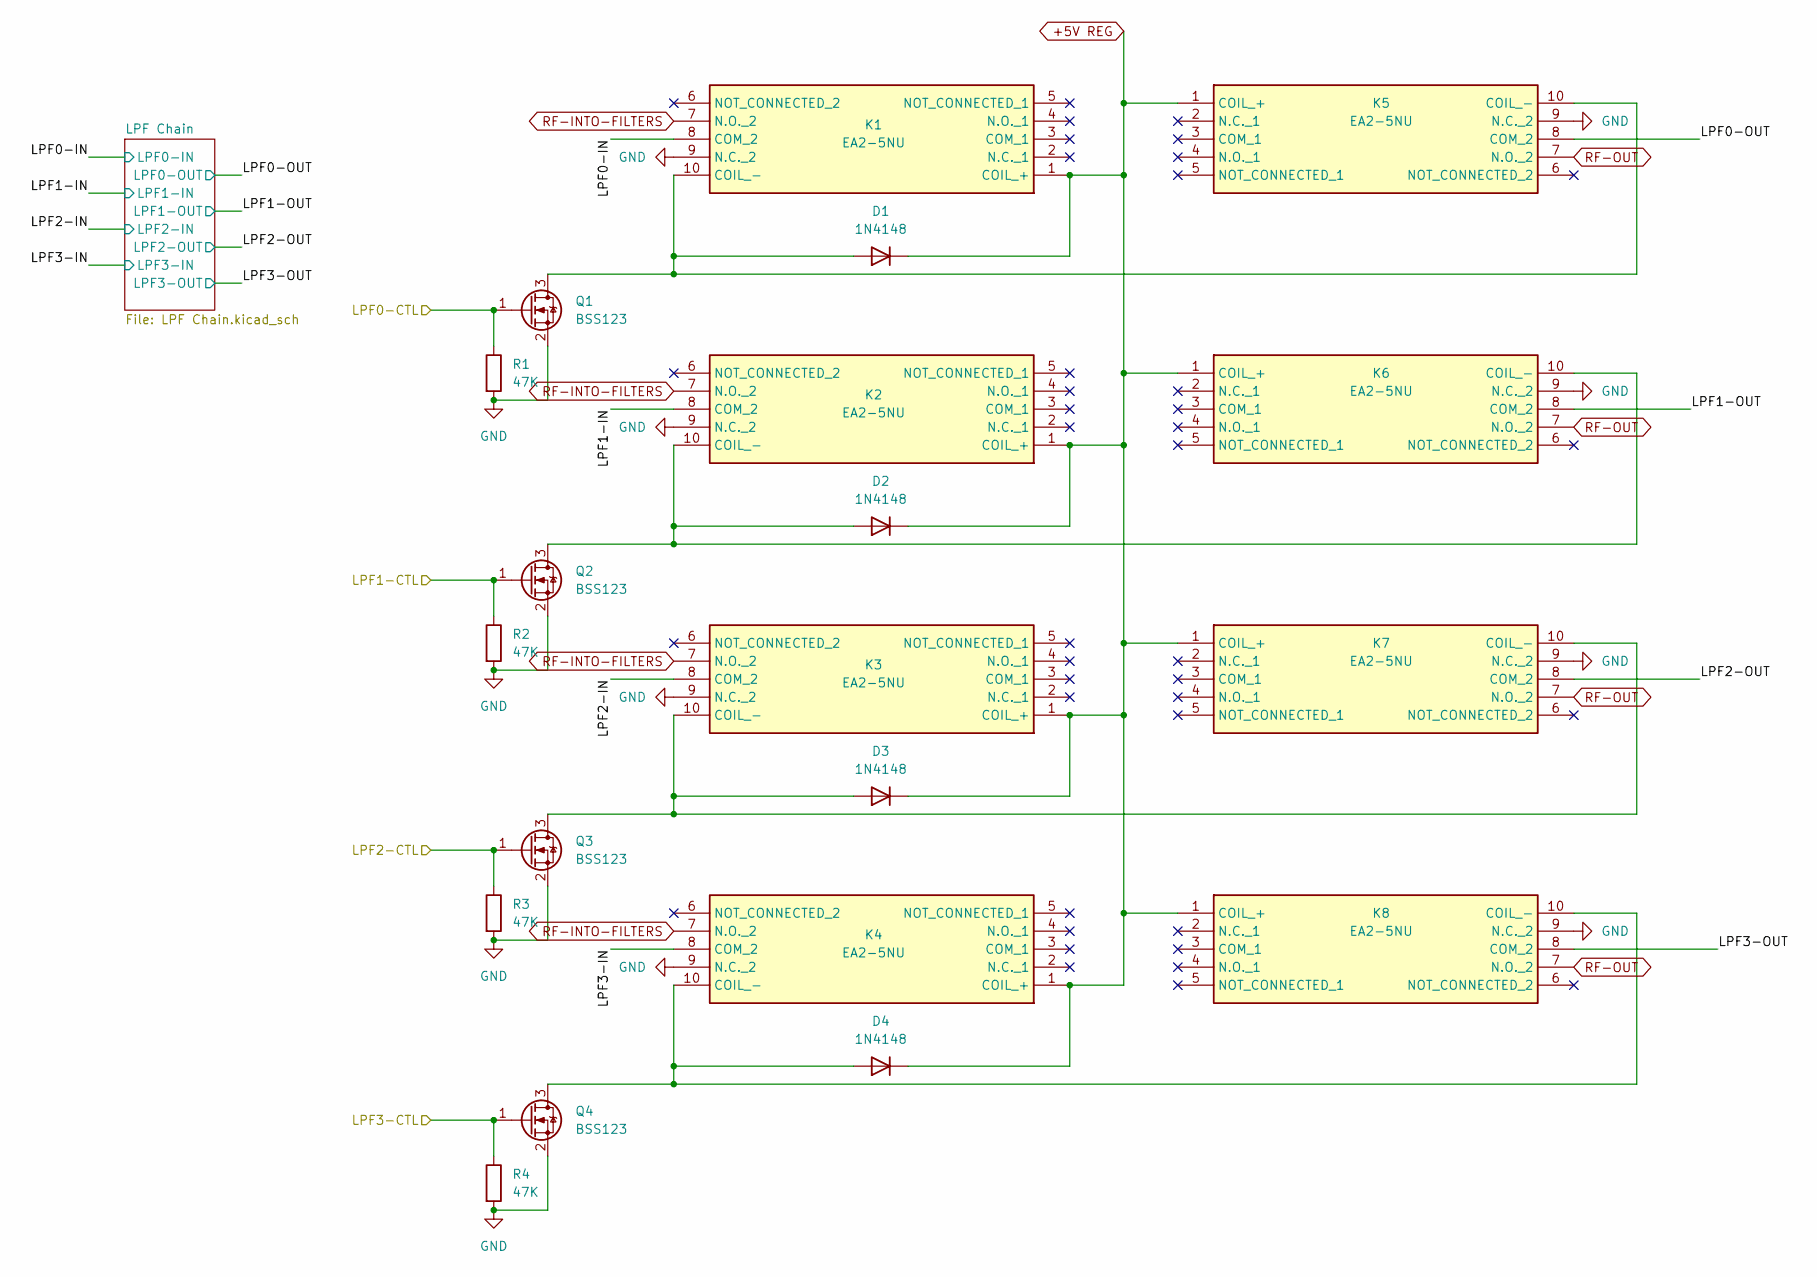
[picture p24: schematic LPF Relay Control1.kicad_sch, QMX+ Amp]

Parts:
D1, D2, D3, D4: 1N4148; D_DO-35_SOD27_P7.62mm_Horizontal
K1, K2, K3, K4, K5, K6, K7, K8: EA2-5NU; DIPS762W70P254L1420H540Q10N; Mouser Part Number 551-EA2-5NU
Q1, Q2, Q3, Q4: BSS123; SOT-23
R1, R2, R3, R4: 47K; R_0805_2012Metric_Pad1.20x1.40mm_HandSolder

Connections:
+3.3V LPF0 CTL from QMX: Q1.1 (G), R1.1; also elsewhere on the board
+3.3V LPF1 CTL from QMX: Q2.1 (G), R2.1; also elsewhere on the board
+3.3V LPF2 CTL from QMX: Q3.1 (G), R3.1; also elsewhere on the board
+3.3V LPF3 CTL from QMX: Q4.1 (G), R4.1; also elsewhere on the board
+5V REG: D1.1 (K), D2.1 (K), D3.1 (K), D4.1 (K), K1.1 (COIL_+), K2.1 (COIL_+), K3.1 (COIL_+), K4.1 (COIL_+), K5.1 (COIL_+), K6.1 (COIL_+), K7.1 (COIL_+), K8.1 (COIL_+); also elsewhere on the board
/LPF Relay Control 1/LPF0-IN: K1.8 (COM_2); also elsewhere on the board
/LPF Relay Control 1/LPF0-OUT: K5.8 (COM_2); also elsewhere on the board
/LPF Relay Control 1/LPF1-IN: K2.8 (COM_2); also elsewhere on the board
/LPF Relay Control 1/LPF1-OUT: K6.8 (COM_2); also elsewhere on the board
/LPF Relay Control 1/LPF2-IN: K3.8 (COM_2); also elsewhere on the board
/LPF Relay Control 1/LPF2-OUT: K7.8 (COM_2); also elsewhere on the board
/LPF Relay Control 1/LPF3-IN: K4.8 (COM_2); also elsewhere on the board
/LPF Relay Control 1/LPF3-OUT: K8.8 (COM_2); also elsewhere on the board
GND: K1.9 (N.C._2), K2.9 (N.C._2), K3.9 (N.C._2), K4.9 (N.C._2), K5.9 (N.C._2), K6.9 (N.C._2), K7.9 (N.C._2), K8.9 (N.C._2), Q1.2 (S), Q2.2 (S), Q3.2 (S), Q4.2 (S), R1.2, R2.2, R3.2, R4.2; also elsewhere on the board
unnamed: D1.2 (A), K1.10 (COIL_-), K5.10 (COIL_-), Q1.3 (D)
unnamed: D2.2 (A), K2.10 (COIL_-), K6.10 (COIL_-), Q2.3 (D)
unnamed: D3.2 (A), K3.10 (COIL_-), K7.10 (COIL_-), Q3.3 (D)
unnamed: D4.2 (A), K4.10 (COIL_-), K8.10 (COIL_-), Q4.3 (D)
RF-INTO-FILTERS: K1.7 (N.O._2), K2.7 (N.O._2), K3.7 (N.O._2), K4.7 (N.O._2); also elsewhere on the board
RF-OUT: K5.7 (N.O._2), K6.7 (N.O._2), K7.7 (N.O._2), K8.7 (N.O._2); also elsewhere on the board

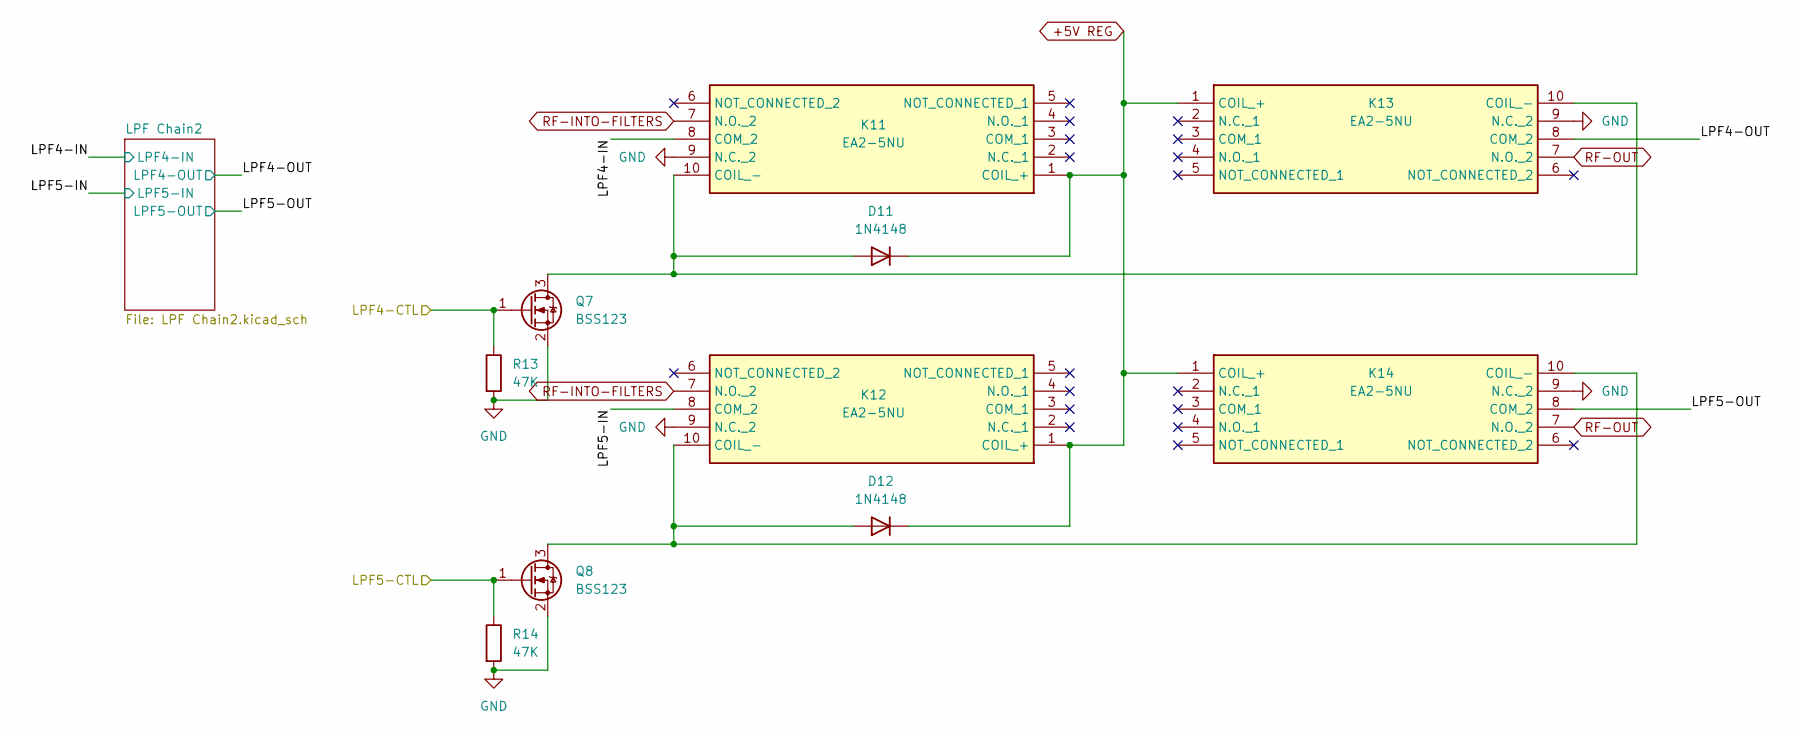
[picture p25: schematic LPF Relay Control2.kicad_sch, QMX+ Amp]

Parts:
D11, D12: 1N4148; D_DO-35_SOD27_P7.62mm_Horizontal
K11, K12, K13, K14: EA2-5NU; DIPS762W70P254L1420H540Q10N; Mouser Part Number 551-EA2-5NU
Q7, Q8: BSS123; SOT-23
R13, R14: 47K; R_0805_2012Metric_Pad1.20x1.40mm_HandSolder

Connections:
+3.3V LPF4 CTL from QMX: Q7.1 (G), R13.1; also elsewhere on the board
+3.3V LPF5 CTL from QMX: Q8.1 (G), R14.1; also elsewhere on the board
+5V REG: D11.1 (K), D12.1 (K), K11.1 (COIL_+), K12.1 (COIL_+), K13.1 (COIL_+), K14.1 (COIL_+); also elsewhere on the board
/LPF Relay Control 2/LPF4-IN: K11.8 (COM_2); also elsewhere on the board
/LPF Relay Control 2/LPF4-OUT: K13.8 (COM_2); also elsewhere on the board
/LPF Relay Control 2/LPF5-IN: K12.8 (COM_2); also elsewhere on the board
/LPF Relay Control 2/LPF5-OUT: K14.8 (COM_2); also elsewhere on the board
GND: K11.9 (N.C._2), K12.9 (N.C._2), K13.9 (N.C._2), K14.9 (N.C._2), Q7.2 (S), Q8.2 (S), R13.2, R14.2; also elsewhere on the board
unnamed: D11.2 (A), K11.10 (COIL_-), K13.10 (COIL_-), Q7.3 (D)
unnamed: D12.2 (A), K12.10 (COIL_-), K14.10 (COIL_-), Q8.3 (D)
RF-INTO-FILTERS: K11.7 (N.O._2), K12.7 (N.O._2); also elsewhere on the board
RF-OUT: K13.7 (N.O._2), K14.7 (N.O._2); also elsewhere on the board

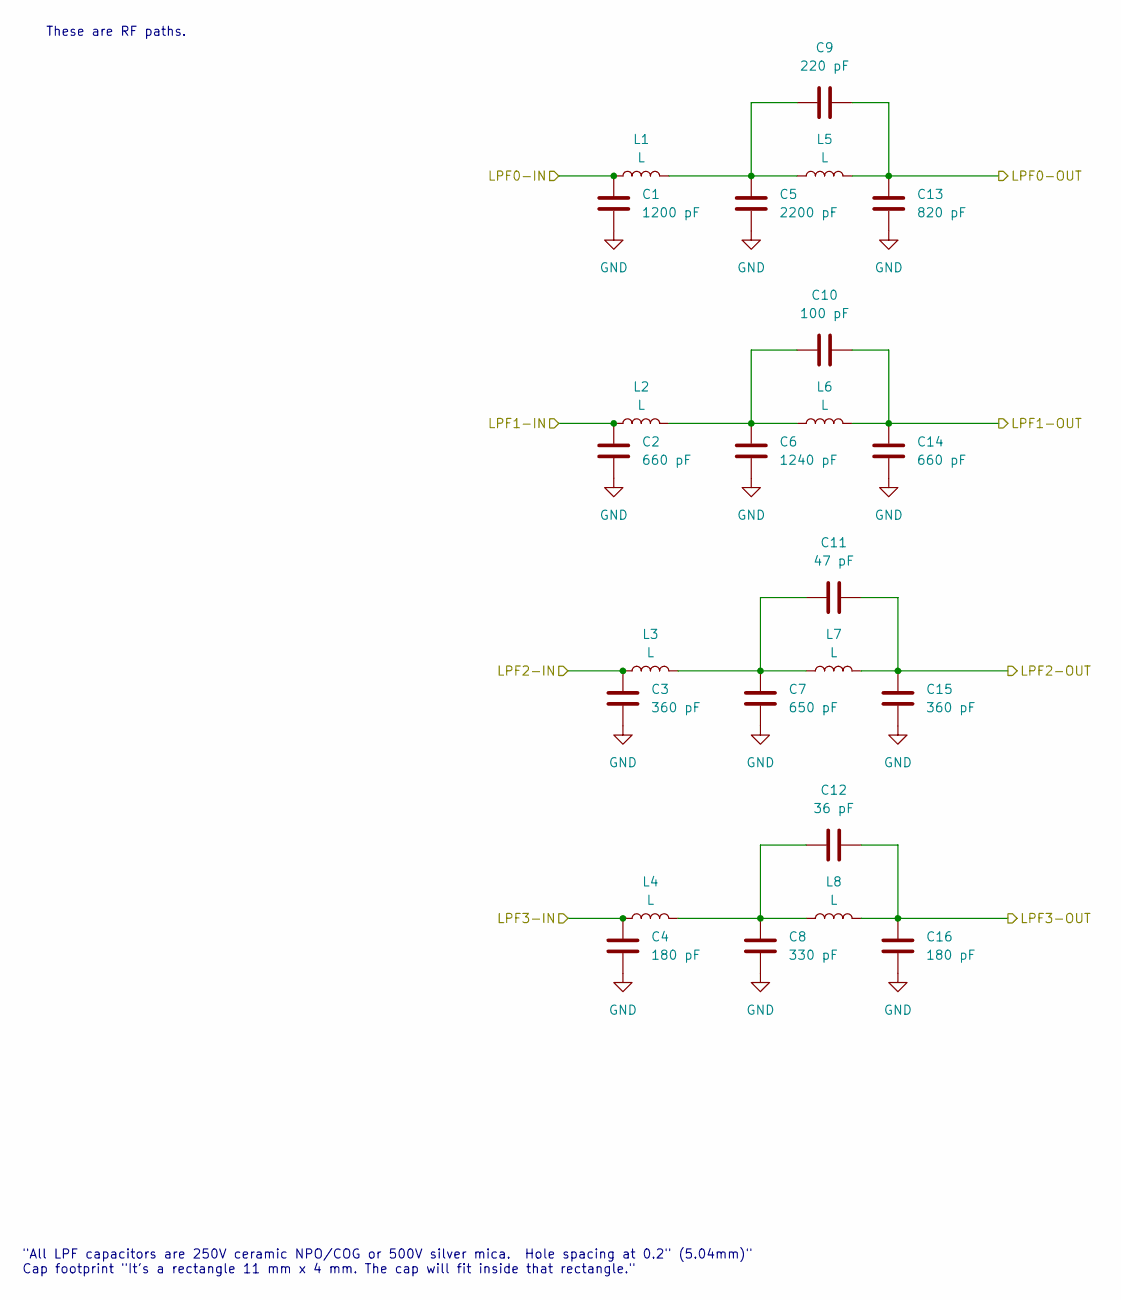
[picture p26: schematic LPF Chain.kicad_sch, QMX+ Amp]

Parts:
C1: 1200 pF; C_Disc_D11.0mm_W3.0mm_P5.00mm
C2, C14: 660 pF; C_Disc_D11.0mm_W3.0mm_P5.00mm
C3, C15: 360 pF; C_Disc_D11.0mm_W3.0mm_P5.00mm
C4, C16: 180 pF; C_Disc_D11.0mm_W3.0mm_P5.00mm
C5: 2200 pF; C_Disc_D11.0mm_W3.0mm_P5.00mm
C6: 1240 pF; C_Disc_D11.0mm_W3.0mm_P5.00mm
C7: 650 pF; C_Disc_D11.0mm_W3.0mm_P5.00mm
C8: 330 pF; C_Disc_D11.0mm_W3.0mm_P5.00mm
C9: 220 pF; C_Disc_D11.0mm_W3.0mm_P5.00mm
C10: 100 pF; C_Disc_D11.0mm_W3.0mm_P5.00mm
C11: 47 pF; C_Disc_D11.0mm_W3.0mm_P5.00mm
C12: 36 pF; C_Disc_D11.0mm_W3.0mm_P5.00mm
C13: 820 pF; C_Disc_D11.0mm_W3.0mm_P5.00mm
L1, L2, L3, L4, L5, L6, L7, L8: L; Toroid_T50_Vertical_L14.0mm_W5.6mm

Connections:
/LPF Relay Control 1/LPF0-IN: C1.1, L1.1; also elsewhere on the board
/LPF Relay Control 1/LPF0-OUT: C9.2, C13.1, L5.2; also elsewhere on the board
/LPF Relay Control 1/LPF1-IN: C2.1, L2.1; also elsewhere on the board
/LPF Relay Control 1/LPF1-OUT: C10.2, C14.1, L6.2; also elsewhere on the board
/LPF Relay Control 1/LPF2-IN: C3.1, L3.1; also elsewhere on the board
/LPF Relay Control 1/LPF2-OUT: C11.2, C15.1, L7.2; also elsewhere on the board
/LPF Relay Control 1/LPF3-IN: C4.1, L4.1; also elsewhere on the board
/LPF Relay Control 1/LPF3-OUT: C12.2, C16.1, L8.2; also elsewhere on the board
GND: C1.2, C2.2, C3.2, C4.2, C5.1, C6.2, C7.2, C8.2, C13.2, C14.2, C15.2, C16.2; also elsewhere on the board
unnamed: C5.2, C9.1, L1.2, L5.1
unnamed: C6.1, C10.1, L2.2, L6.1
unnamed: C7.1, C11.1, L3.2, L7.1
unnamed: C8.1, C12.1, L4.2, L8.1

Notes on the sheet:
These are RF paths.
"All LPF capacitors are 250V ceramic NPO/COG or 500V silver mica. Hole spacing at 0.2" (5.04mm)" Cap footprint "It's a rectangle 11 mm x 4 mm. The cap will fit inside that rectangle."

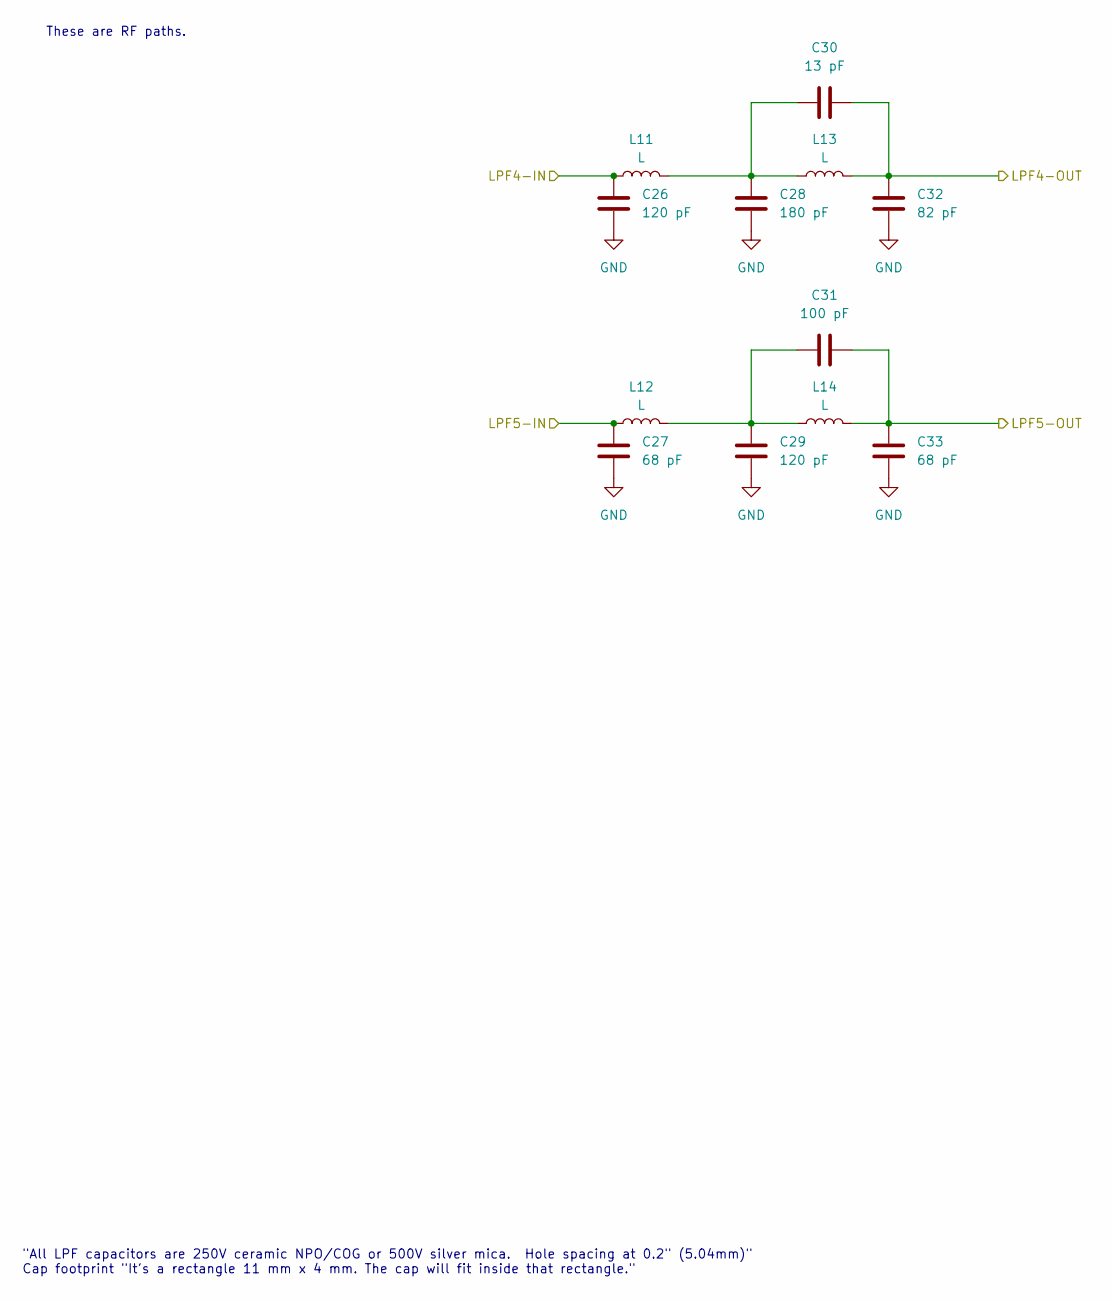
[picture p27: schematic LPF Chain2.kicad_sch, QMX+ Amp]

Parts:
C26, C29: 120 pF; C_Disc_D11.0mm_W3.0mm_P5.00mm
C27, C33: 68 pF; C_Disc_D11.0mm_W3.0mm_P5.00mm
C28: 180 pF; C_Disc_D11.0mm_W3.0mm_P5.00mm
C30: 13 pF; C_Disc_D11.0mm_W3.0mm_P5.00mm
C31: 100 pF; C_Disc_D11.0mm_W3.0mm_P5.00mm
C32: 82 pF; C_Disc_D11.0mm_W3.0mm_P5.00mm
L11, L12, L13, L14: L; Toroid_T50_Vertical_L14.0mm_W5.6mm

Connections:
/LPF Relay Control 2/LPF4-IN: C26.1, L11.1; also elsewhere on the board
/LPF Relay Control 2/LPF4-OUT: C30.2, C32.1, L13.2; also elsewhere on the board
/LPF Relay Control 2/LPF5-IN: C27.1, L12.1; also elsewhere on the board
/LPF Relay Control 2/LPF5-OUT: C31.2, C33.1, L14.2; also elsewhere on the board
GND: C26.2, C27.2, C28.1, C29.2, C32.2, C33.2; also elsewhere on the board
unnamed: C28.2, C30.1, L11.2, L13.1
unnamed: C29.1, C31.1, L12.2, L14.1

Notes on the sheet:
These are RF paths.
"All LPF capacitors are 250V ceramic NPO/COG or 500V silver mica. Hole spacing at 0.2" (5.04mm)" Cap footprint "It's a rectangle 11 mm x 4 mm. The cap will fit inside that rectangle."

Board: 2 copper layers, 101 parts (0 on the bottom side), 52 nets, no tracks yet.

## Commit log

2024-08-05 PCB template now fits the QMX dead space
    [QMX-amp.kicad_pcb, QMX-amp.kicad_sch]
2024-08-05 starting working on schematic. struggling with relays
    [QMX-amp.kicad_sch, untitled.kicad_sch]
2024-08-07 made some progress on LPF Relay Control sheet. Looks like it will span two sheets
    [LPF Relay Control1.kicad_sch, QMX-amp.kicad_sch, untitled.kicad_sch]
2024-08-08 Working on LPF control and actual filters. They are intertwingled pretty tightly. Also ran ERC and beat out some errors.
    [LPF Relay Control1.kicad_sch, QMX-amp.kicad_sch]
2024-08-08 moved LPF0 to LPF as I can fit them all into one schematic
    [LPF Relay Control1.kicad_sch, LPF.kicad_sch, LPF0.kicad_sch]
2024-08-08 rm LPF0.kicad_sch now that it's been moved
    [LPF0.kicad_sch]
2024-08-08 placed LPF chains in sub-schematic. ERC passes
    [LPF Relay Control1.kicad_sch, LPF.kicad_sch]
2024-08-09 checkpoint progress, working on LPF chains
    [LPF Relay Control1.kicad_sch, QMX-amp.kicad_sch]
2024-08-09 fleshed out LPF chains. ERC passes
    [LPF Relay Control1.kicad_sch, LPF.kicad_sch]
2024-08-09 added RF through LPF chains
    [LPF Relay Control1.kicad_sch, LPF.kicad_sch, QMX-amp.kicad_sch]
2024-08-09 worked on strange stuff on btm of LPF filter chain schematic. ERC passes
    [LPF Relay Control1.kicad_sch, LPF-Chain-Bypass.kicad_sch, QMX-amp.kicad_sch]
2024-08-09 LPF chains, all caps now normal; missing inducator added. ERC passes
    [LPF.kicad_sch]
2024-08-10 last of v0.1. Ron stopped by with many corrections for me
    [QMX-amp.kicad_sch, amp.kicad_sch, power.kicad_sch]
2024-08-10 all caps on LPF Chain are pF. rest are uF
    [LPF Relay Control1.kicad_sch, LPF-Chain-Bypass.kicad_sch, LPF.kicad_sch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]
2024-08-10 RF-IN-PAST-SW now RF-INTO-FILTERS
    [LPF Relay Control1.kicad_sch, LPF-Chain-Bypass.kicad_sch]
2024-08-10 I think all the caps have units now
    [amp-relay-ckt.kicad_sch]
2024-08-10 does NOT pass ERC. Something going on with LM7805
    [amp-relay-ckt.kicad_sch]
2024-08-10 +5V REG now connected to all LPF relay coils
    [LPF Relay Control1.kicad_sch, QMX-amp.kicad_sch]
2024-08-10 trying to get K1 & K2 appear in multiple places, yet be recognized as identical. Currently reporting dup K1
    [LPF Relay Control1.kicad_sch, LPF-Chain-Bypass.kicad_sch, amp-relay-ckt.kicad_sch]
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2024-08-11 checkpoint progress from 240810
    [LPF-Chain-Bypass.kicad_sch, amp-relay-ckt.kicad_sch]
2024-08-11 changed +5V and +12V from global symbol to the more normal voltage busses
    [LPF-Chain-Bypass.kicad_sch, QMX-amp.kicad_sch, amp-relay-ckt.kicad_sch]
2024-08-11 could not figure out how to have two instances of K1 so I used global labels. STINKY HACK
    [LPF-Chain-Bypass.kicad_sch, amp-relay-ckt.kicad_sch]
2024-08-11 added cap values to filter chain per Ron
    [LPF Relay Control1.kicad_sch, LPF-Chain-Bypass.kicad_sch, LPF.kicad_sch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]
2024-08-11 ERC passes again. The transistor in front of LM7805 is a switch, so PWR_FLAG doesn't cross over unless I'm explicit
    [amp-relay-ckt.kicad_sch]
2024-08-11 rm amp.kicad_sch. Vestigial. Interfering with progress
    [amp.kicad_sch]
2024-08-12 checkpoint progress from Sunday 240811
    [LPF Relay Control1.kicad_sch, LPF-Chain-Bypass.kicad_sch, LPF.kicad_sch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]
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2024-08-12 working on Amp. Stuck on symbol for RD16HHF1
    [LPF Relay Control1.kicad_sch, LPF-Chain-Bypass.kicad_sch, LPF.kicad_sch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]
2024-08-12 modeled RD16HHF1 and added it to Amp. ERC passes
    [amp.kicad_sch]
2024-08-12 first pass at amp ckt. had to create a few parts, so these should be checked VERY carefully
    [LPF Relay Control1.kicad_sch, LPF-Chain-Bypass.kicad_sch, LPF.kicad_sch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]
2024-08-12 changed symbol for RD16HHF1 to be more like BSS123, per Ron
    [amp.kicad_sch]
2024-08-12 got rid of K11 which was alias for K2. Figured out RELAY-SYNC as a way of making sure K1 & K2 operate in sync
    [LPF-Chain-Bypass.kicad_sch, amp-relay-ckt.kicad_sch]
2024-08-13 v0.6 ERC passes. I went over it with a fine tooth comb and corrected lots of little stuff. Ron should review all the components I have to create very carefully. In particular, MPS-751 symbol does not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
    [LPF Relay Control1.kicad_sch, LPF-Chain-Bypass.kicad_sch, LPF.kicad_sch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]
2024-08-13 v0.7 fixed MPS-751 and bifilar on FT50-43. ERC passes
    [LPF Relay Control1.kicad_sch, LPF-Chain-Bypass.kicad_sch, LPF.kicad_sch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]
2024-08-14 gave RD16HHF1 an TO-220 footprint
    [amp.kicad_sch]
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2024-08-18 I think I am working on picking parts
    [LPF.kicad_sch, amp.kicad_sch]
2024-08-18 created 11x4mm footprint with 5mm pin spacing for caps on LPF per Ron
    [LPF Relay Control1.kicad_sch, LPF-Chain-Bypass.kicad_sch, LPF.kicad_sch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]
2024-08-18 ron came by and gave lots of feedback. many notes on schematic for additional changes
    [LPF Relay Control1.kicad_sch, QMX-amp.kicad_sch, amp-relay-ckt.kicad_sch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]
2024-08-19 checkpoint changes
    [QMX-amp.kicad_sch]
2024-08-19 v0.8 after much hacking of BS audio footprint from Digikey we now have a 3.5mm audio jack wired in. ERC pass
    [LPF Relay Control1.kicad_sch, LPF-Chain-Bypass.kicad_sch, LPF.kicad_sch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]
2024-08-19 expended to all 6 LPFs. ERC pass. Need to check component values on new LPF page
    [LPF Chain.kicad_sch, LPF Chain2.kicad_sch, LPF Relay Control1.kicad_sch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]
2024-08-19 v0.9 ERC passes. All parts have footprints. Need to renumber pages so things related are closer in printout
    [LPF Chain.kicad_sch, LPF Chain2.kicad_sch, LPF Relay Control1.kicad_sch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]
2024-08-19 checkpoint before I shrink width of capps so things might fit PCB
    [LPF Chain.kicad_sch, LPF Chain2.kicad_sch, LPF Relay Control1.kicad_sch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]
2024-08-19 v0.10 after slimming down capacitor width to 3mm so it *barely* fits.
    [LPF Chain.kicad_sch, LPF Chain2.kicad_sch, QMX-amp.kicad_pcb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]
2024-08-20 whatever changes happened?
    [QMX-amp.kicad_pcb]
2024-08-20 Ron helped moved all the parts into PCB
    [LPF Relay Control1.kicad_sch, LPF Relay Control2.kicad_sch, QMX-amp.kicad_pcb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]
2024-08-22 worked on netclasses for 12VPWR and RF
    [LPF Chain.kicad_sch, LPF Chain2.kicad_sch, LPF Relay Control1.kicad_sch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]
2024-11-11 finish renaming to QMX-Plus-amp
    [QMX-Plus-amp.kicad_pcb, QMX-Plus-amp.kicad_sch]
